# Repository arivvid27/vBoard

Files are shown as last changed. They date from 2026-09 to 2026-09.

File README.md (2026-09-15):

# vBoard

## Overview
This project is a custom-built mechanical keyboard created to replace a failing, non-ergonomic office keyboard used by my English teacher, which was causing him noticeable hand strain during long grading sessions. 

The goal was to build a reliable, tactile, and comfortable typing tool tailored for high-volume daily classroom use.

## Why I Built It
* **Solving a Real Problem:** Standard membrane office keyboards lack tactile feedback, force heavy bottom-outs, and offer no ergonomic support. Watching a favorite teacher struggle with physical discomfort on a broken board made this a high-impact problem to solve.
* **Hands-on Curiosity:** I had always wanted to build a custom mechanical keyboard from scratch to learn about hardware assembly, switch physics, and custom keymapping.

## Features & Specs
* **Ergonomic Layout:** Compact footprint designed to reduce unnecessary reach and wrist movement.
* **Tactile Switches:** Selected for clear physical feedback without requiring excessive actuation force, helping reduce finger fatigue.
* **Custom Keycaps:** Clean, comfortable profile designed for long typing sessions.

## What I Learned
* **Hardware Assembly:** Learned component compatibility across PCBs, plates, switches, and stabilizers, along with basic soldering and hardware assembly.
* **Ergonomics & Physical Health:** Explored how keycap profiles, switch actuation points, and board angles directly affect wrist strain and overall typing comfort.
* **Firmware Configuration:** Discovered how to program custom keymaps and function layers to streamline everyday typing and shortcut tasks.

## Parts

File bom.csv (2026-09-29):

Item Description | Unit Price ($) | Quantity Ordered | Total Price ($) | Amazon Link
EEEEE 1N4148 Through-Hole Switching Diodes (150pcs) | 5.99 | 1 | 5.99 | https://www.amazon.com/dp/B0FC289DVH
Fgruh 1120PCS M3 Socket Cap Screws Assortment Kit (Alloy Steel) | 9.99 | 1 | 9.99 | https://www.amazon.com/dp/B0FGV5FCBN
DUROCK Stabilizer V3, PCB Mount Screw-in (Smokey 100% Kit) | 22.99 | 1 | 22.99 | https://www.amazon.com/dp/B0B2RXR22X
DUROCK MX Hotswap PCB Sockets (Black, 110pcs) | 12.99 | 1 | 12.99 | https://www.amazon.com/dp/B0B4W9YMGM
HONKID Keyboard Plate Foam, Sound Dampening Poron (Black, 3mm) | 12.99 | 1 | 12.99 | https://www.amazon.com/dp/B0B4JXKNDQ
HONKID Keyboard Case Foam, Sound Dampening Poron (Black, 2mm) | 11.99 | 1 | 11.99 | https://www.amazon.com/dp/B0B151N6V4
GUNMJO Pro Custom Coiled USB C Cable with Aviator (White, 1.5M) | 19.99 | 1 | 19.99 | https://www.amazon.com/dp/B09F5YBH6Z
New Fashion Kingdom Stainless Steel Keycap & Switch Puller Kit | 5.98 | 1 | 5.98 | https://www.amazon.com/dp/B08TSSJ8Q3
Womier PBT Custom Blue Keycaps Set (Cherry Profile, 138 Keys) | 16.99 | 1 | 16.99 | https://www.amazon.com/dp/B0D3BW6R11
Akko V3 Creamy Blue Pro Tactile Switches (45pcs per box) | 10.39 | 3 | 31.17 | https://www.amazon.com/dp/B0C3H7PR1Z
Heat-Set Threaded Inserts M3 Heat Set Insert | 8.99 | 1 | 8.99 | https://www.amazon.com/gp/product/B0CS6VZYL8
Bumper Pads Self-Adhesive | 9.09 | 1 | 9.09 | https://www.amazon.com/gp/product/B0CF5CX3M3
Brass Flat Bar 6in x 2in x 0.12in | 11.89 | 1 | 11.89 | https://www.amazon.com/gp/product/B0F31ZW3QQ
Orpheus Pico (RP2040) | ?? | 1 | ?? | ??

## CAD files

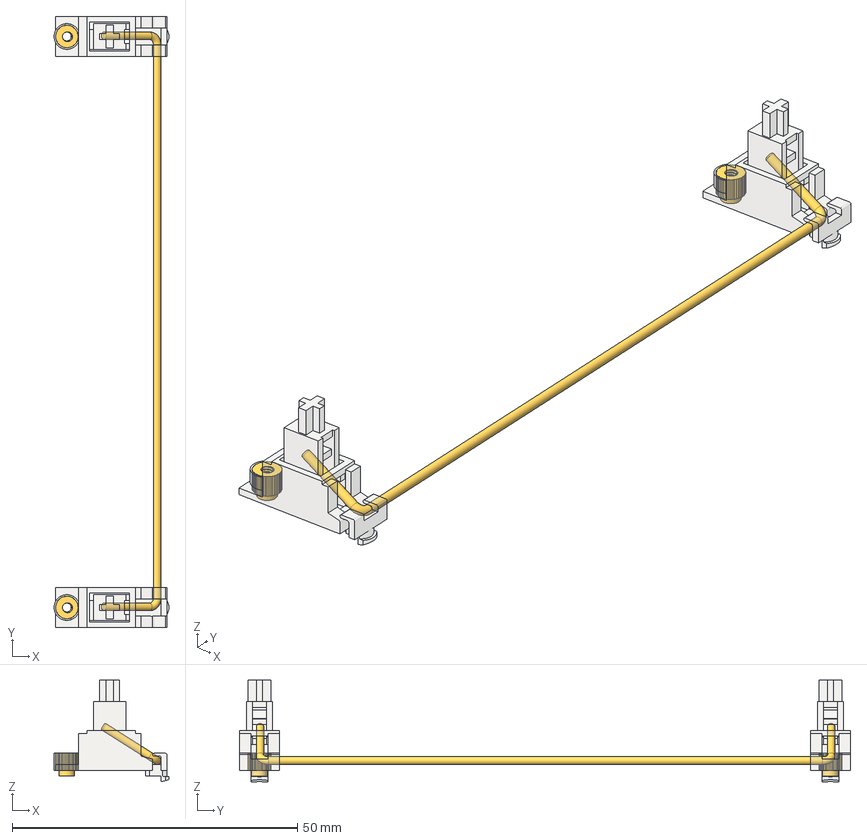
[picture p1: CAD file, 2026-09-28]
CAD FILES/6.25U Stabilizer.step
20.1 x 107.0 x 17.8 mm
Stabilizer Housing x 2
M2 Insert x 2
Stabilizer Insert x 2
6.25U Stabilizer Bar

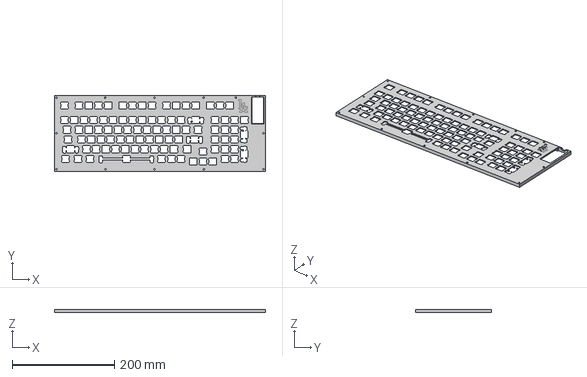
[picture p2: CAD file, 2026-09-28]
CAD FILES/FINAL/Switch Plate.step
413.5 x 148.4 x 6.50 mm

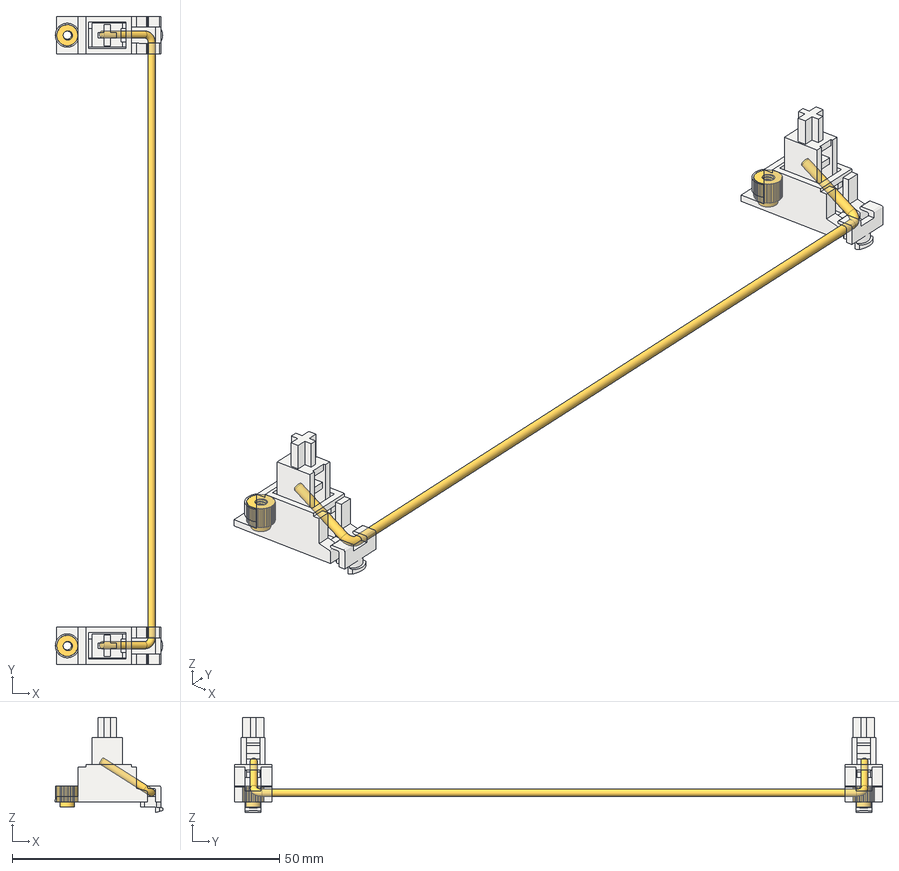
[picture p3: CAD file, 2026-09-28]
CAD FILES/7U Stabilizer.step
20.1 x 121.3 x 17.8 mm
Stabilizer Housing x 2
M2 Insert x 2
Stabilizer Insert x 2
7U Stabilizer Bar

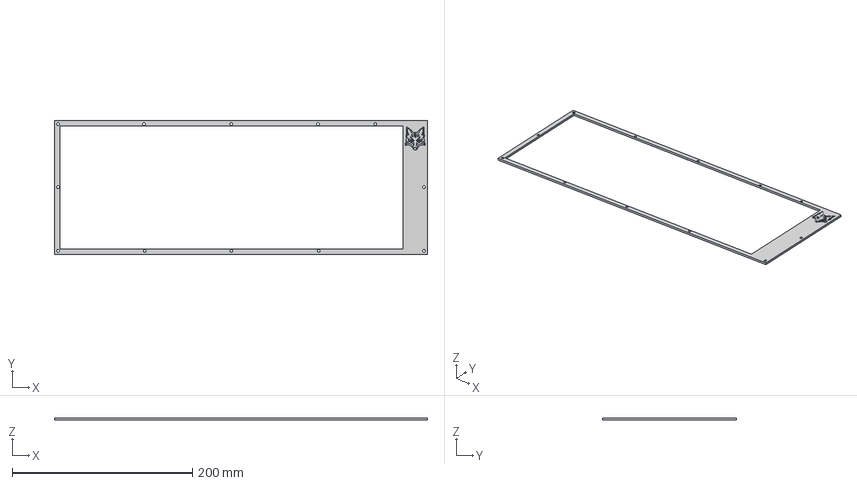
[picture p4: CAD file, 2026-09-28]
CAD FILES/FINAL/Top Frame.step
413.5 x 148.4 x 2.50 mm

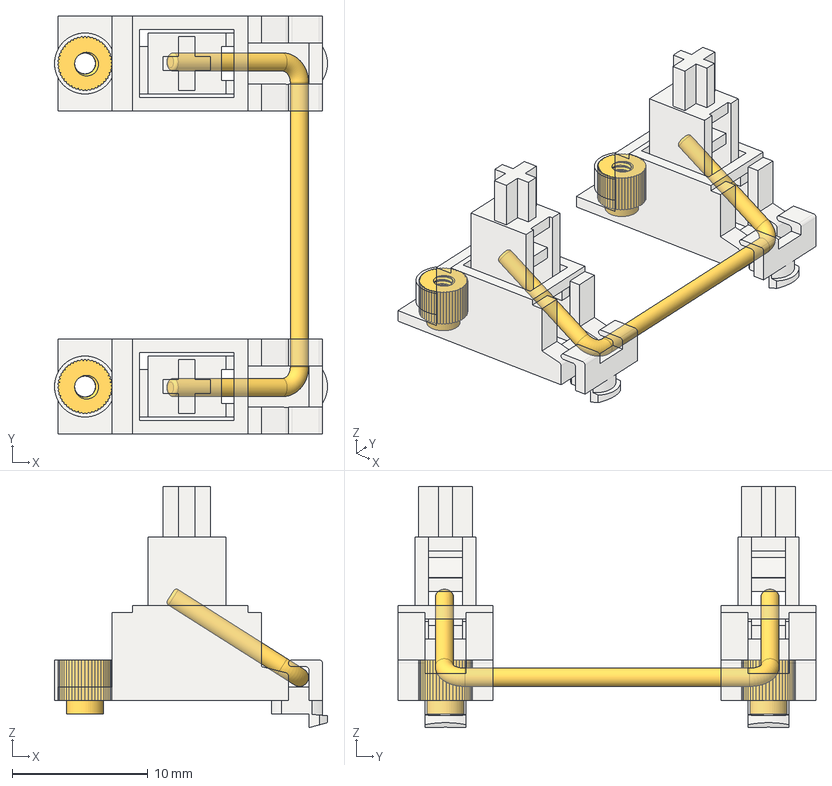
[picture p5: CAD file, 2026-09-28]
CAD FILES/2U Stabilizer.step
20.1 x 30.8 x 17.8 mm
Stabilizer Housing x 2
M2 Insert x 2
Stabilizer Insert x 2
2U Stabilizer Bar

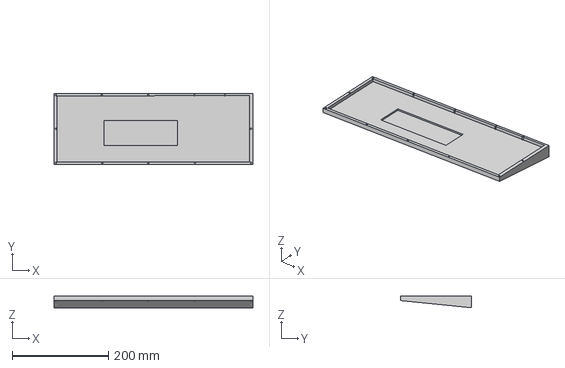
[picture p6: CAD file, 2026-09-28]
CAD FILES/FINAL/Bottom Plate.step
413.5 x 148.4 x 23.9 mm

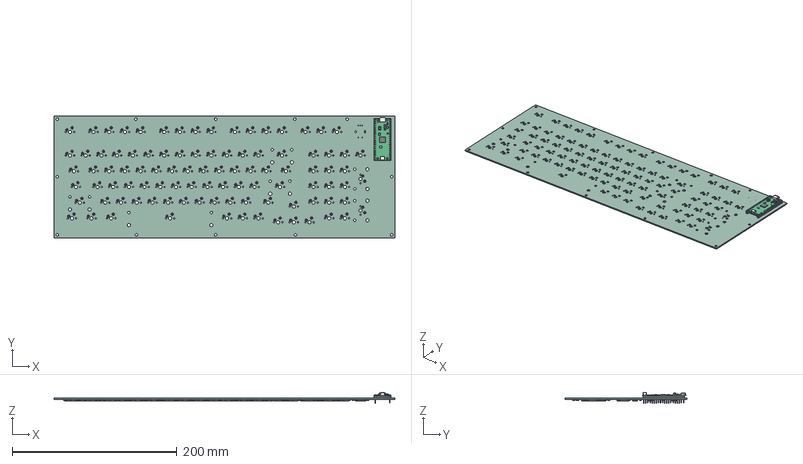
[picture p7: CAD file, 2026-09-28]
CAD FILES/vBoard.step
413.5 x 148.4 x 12.8 mm
RaspberryPi_Pico_H_Module_KiCad
RaspberryPi_Pico_Header_DIP-40_H2.54mm_KiCad
Contact x 194
D_SOD-123 x 98
vBoard_PCB

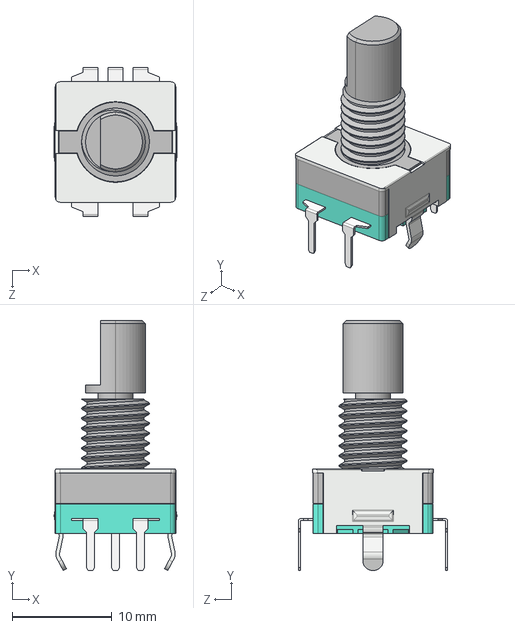
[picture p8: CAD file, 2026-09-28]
CAD FILES/EC11.STEP
12.3 x 25.1 x 15.0 mm

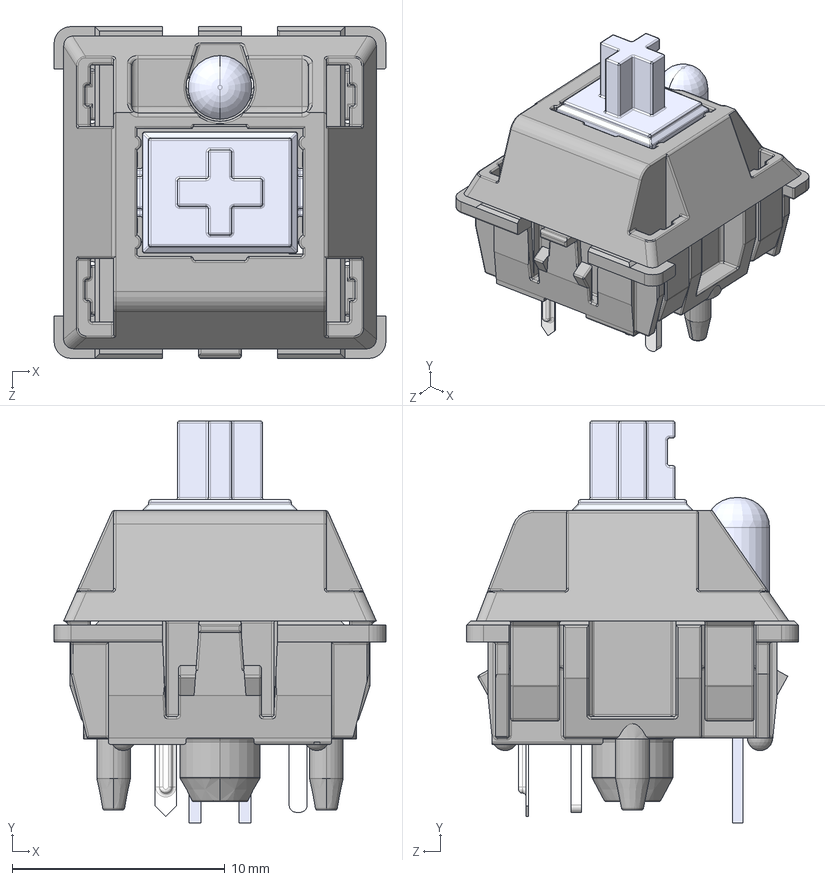
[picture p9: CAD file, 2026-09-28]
CAD FILES/MX.STEP
15.6 x 18.9 x 15.6 mm
MX 轴 按键′_ü___¨1
MX 轴 轴体áì_¨￠¨__
MX粣 拸簽LEDLEDLED
MX轴 轴体 底部 μ×2__默认_á2____è_
针脚___默认__è_

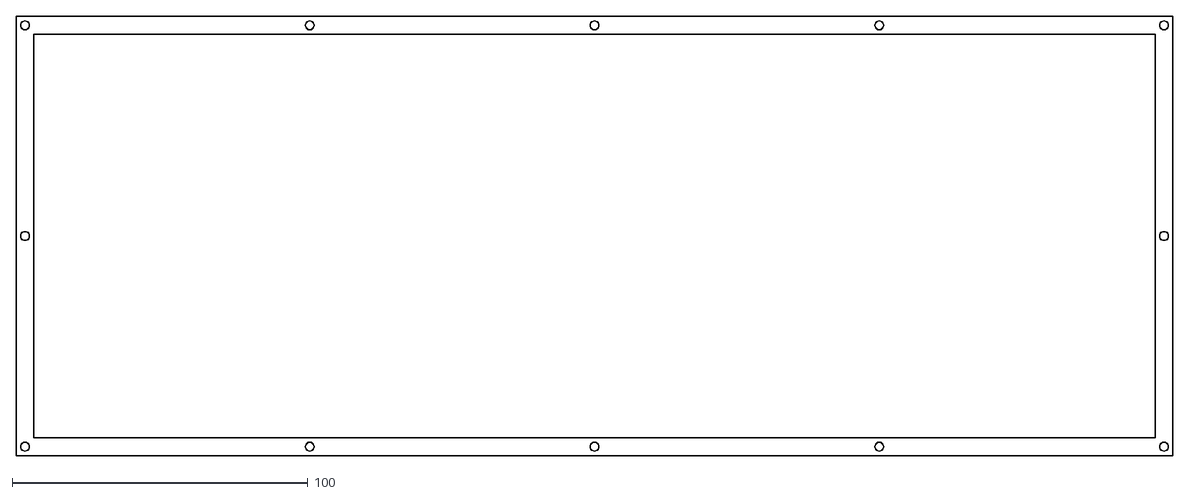
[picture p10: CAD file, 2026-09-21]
CAD FILES/closerlayer.dxf
391.5 x 148.6

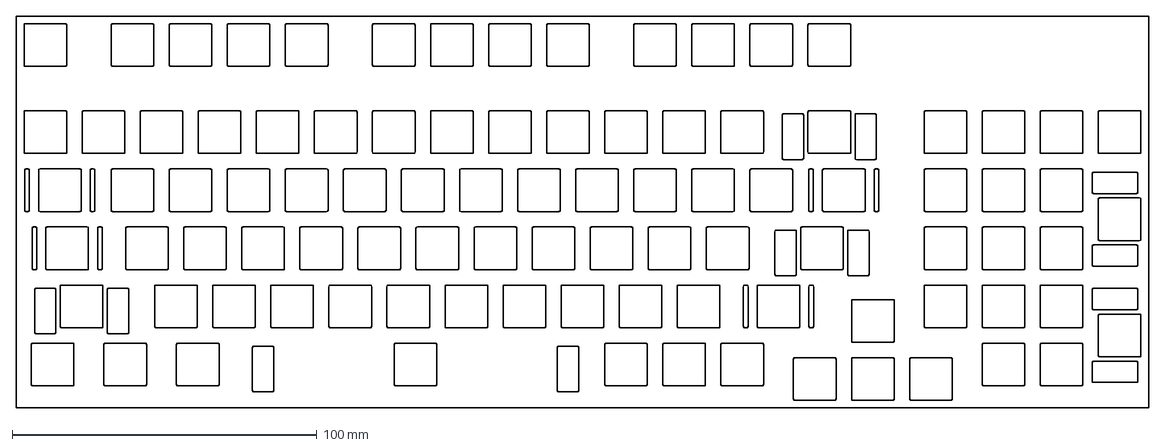
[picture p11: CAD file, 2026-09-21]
CAD FILES/switchlayer.dxf
371.5 x 128.6 mm

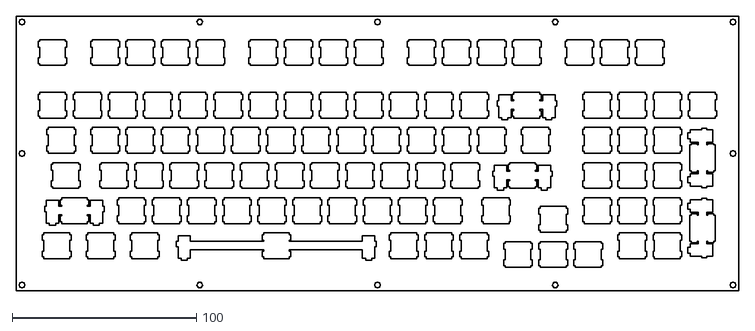
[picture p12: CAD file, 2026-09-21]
CAD FILES/switchlayerv2.dxf
391.5 x 148.6

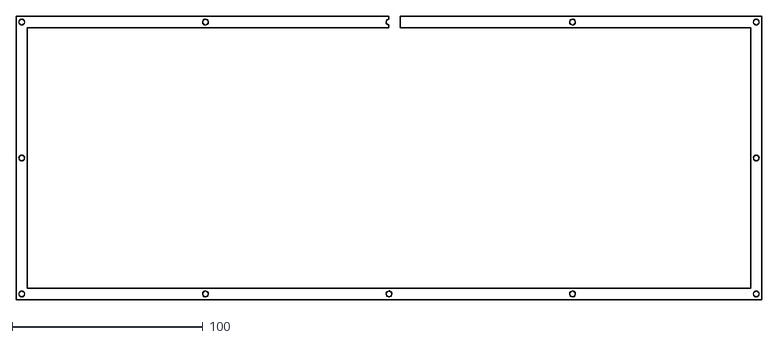
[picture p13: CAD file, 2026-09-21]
CAD FILES/openlayer.dxf
391.5 x 148.6

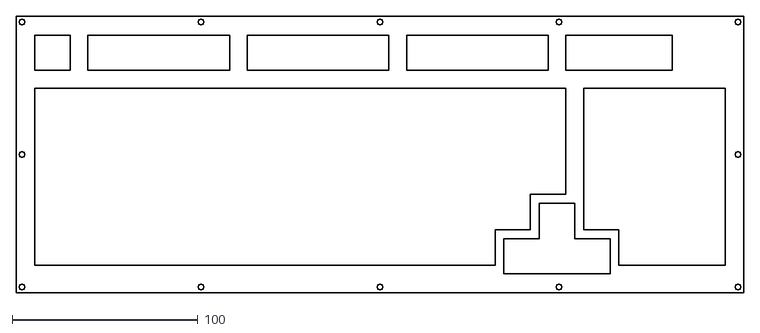
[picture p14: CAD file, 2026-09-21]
CAD FILES/toplayer.dxf
391.5 x 148.6

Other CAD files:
CAD FILES/botplate.dxf

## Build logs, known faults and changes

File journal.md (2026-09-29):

# vBoard - Build Journal

A running log of me building vBoard, a 96% / 1800-compact mechanical keyboard for my English teacher. Running an Orpheus Pico (RP2040) and RMK for firmware.

Times are rough, i just eyeball it and round to the nearest half hour.

---

## Sept 1 - Getting the idea down / research

Spent the first bit just figuring out what i actually want to build. My english teacher's office keyboard is basically falling apart and he's always complaining his hands hurt after grading, so i figured a custom mech board would be a cool thing to make for him. Watched a bunch of youtube build vids and read some geekhack + keebtalk threads to get a feel for what im getting into.

Also looked into layouts. I want something that keeps the numpad since he's entering grades all day, but i dont want a full fat fullsize. Landed on a 96% / 1800-compact. You get the numpad and arrows but everything is smushed together so it takes way less desk space. Seems perfect for his cramped desk.

~1 hr

---

## Sept 2 - Layout decisions + controller pick

Kept going on the 96% thing. Made a rough list in my notes of everything i think i'll need - pcb, plate, case, switches, stabs, keycaps, diodes, sockets, controller. Realized theres a LOT of little parts i wasnt thinking about (screws, foam, etc).

Big decision today was the controller. Instead of designing around a raw rp2040 chip and dealing with the usb + crystal + power stuff myself, im gonna use an Orpheus Pico. Its basically a rpi pico footprint running the RP2040 so i can socket it and not have to reflow a tiny qfn chip on my first ever pcb. Way less scary. Definately going with RMK for the firmware too since its rust based and i want to learn rust anyway, and it supports the rp2040 fine.

~0.5 hr

---

## Sept 3 - KiCad install + libraries (setup)

Downloaded and installed KiCad. Took a little while cuz the installer is chonky. Then spent most of the time getting libraries set up - grabbed the keyswitch kicad library and the kbd footprint libs so i have MX hotswap footprints and stab cutouts ready to go. Also pulled in a diode footprint set.

Had a dumb issue where kicad couldnt find the footprint tables, had to go into preferences and manually point it at the library paths. Fixed eventually. Made a github repo for the project too so everything is backed up.

~1 hr (setup)

---

## Sept 4 - Figuring out the CAD side (setup)

The case is gonna be a stacked/sandwich design - a bunch of flat layers screwed together with M3 screws. For now im not doing any 3d modeling, just 2d drawings of each layer that i can send off to get laser cut. So this session was me figuring out my drawing workflow and how to get clean DXF profiles out.

Im a software person, not a mechanical one, so honestly all of this cad stuff is new to me. Did a couple beginner 2d sketching tutorials so my outlines come out as proper closed loops. No real drawing yet, just getting my head around it.

~1 hr (setup)

---

## Sept 5 - BOM (setup)

Sat down and actually built out my bill of materials. Went thru amazon and picked out everything, put it in a bom.csv so i can track prices. Heres the gist:

- SK6812-E reverse mount rgb leds (for per key rgb, the reverse mount ones shine thru the switch)
- 1N4148 diodes for the matrix
- M3 socket cap screw kit for holding the case layers together
- Durock V3 screw in stabilizers (smokey)
- Durock MX hotswap sockets so i dont have to solder every switch
- plate foam (3mm poron) + case foam (2mm poron) for sound
- coiled usb c cable cuz it looks cool
- switch + keycap puller kit
- Womier PBT keycaps, cherry profile, blue
- Akko V3 Creamy Blue Pro tactile switches (got 3 boxes, 45 each = 135, enough for a 96% with spares)

Total came out to around $160ish which isnt bad. Double checked the switch count against how many keys a 1800 layout has, should be fine with a few extra.

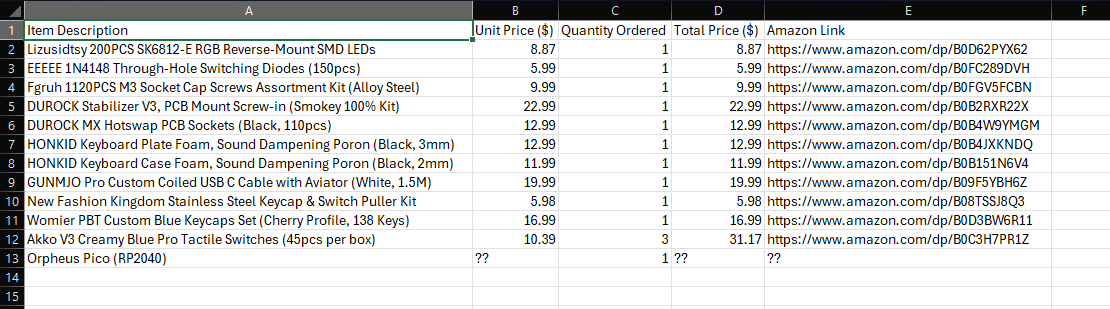
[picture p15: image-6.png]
BOM


~1 hr (setup)

---

## Sept 6 - Planning the layout in KLE + CAD drawings start

Built the exact 96% layout in keyboard layout editor (KLE) first so i know where every key sits and what size it is. Getting the 1800 arrangement right is fiddly - the arrow keys and nav cluster get tucked in tight and the numpad has to line up on the right. Once it looked right i used it as my reference for drawing.

Then started the actual case layer drawings. These are just 2d drawings for now, one profile per layer, that ill get laser cut. Got the outer profile done first so i can reuse it across every layer. This is my first time really doing cad so its slow going, lots of undo.

~2 hr

---

## Sept 8 - More layer drawings

Kept going on the layers. Reused the outer profile across the stack:
- top layer (bezel that frames the keycaps)
- switch layer / plate (all the switch cutouts)
- open + closer layers (spacers for depth / to hide the pcb edge)
- bottom plate (the base)

Being a swe and not a mech engineer, laying out precise dimensioned cutouts is a whole different brain than writing code. Took me a while to get comfy with constraints and getting things to actually snap where i want. Got the easy layers (top, bottom, spacers) mostly done.

~2 hr

---

## Sept 9 - Switch cutout grind

The switch plate is the painful one - gotta cut a 14x14mm hole for every single switch, ~100 of them, all positioned off my KLE layout. Spent basically the whole session just placing and lining up switch cutouts. Very tedious and i kept second guessing my spacing (19.05mm grid) so i measured a bunch of times.

Got most of the switch cutouts placed. My eyes hurt lol.

~1.5 hr

---

## Sept 11 - Stabilizer cutouts

Did the stabilizer cutouts for the bigger keys (spacebar, both shifts, enter, backspace, numpad plus/enter). Looked up the official durock v3 stab cutout dimensions cuz my first attempt was just plain rectangles that were the wrong shape. Redid them properly.

Learning as i go how much little details matter in mechanical stuff - a cutout being half a mm off actually matters here, which is not something i deal with in software. Slow but getting there.

~1.5 hr

---

## Sept 13 - v2 switch layer + screw holes

Realized my switch cutouts were a hair too tight for the switch clips to actually seat, so i did a v2 of the switch layer with slightly cleaner cutouts. Then added all the M3 screw holes across the layers - corners plus a few in the middle so the plate doesnt bow.

The important part was making the screw holes line up across every single layer so one screw can pass straight thru the whole stack. Went hole by hole checking alignment. Found a couple that were off and fixed them.

~1.5 hr

---

## Sept 15 - Fitment check + DXF cleanup

Went over all the layer drawings and imagined the whole stack together - screw holes have to pass thru clean, plate cutouts have to sit over where the switches go. Fixed one hole that was off by about a mm so a screw wouldnt go straight.

Then cleaned up the DXFs for export. When you export you sometimes get little duplicate lines or tiny gaps that mess up a laser cutter, so i went thru each layer (toplayer, switchlayer + v2, openlayer, closerlayer, botplate) and made sure every profile is one closed loop with no doubles. Pushed everything to github too.

~2 hr

---

## Sept 16 - Trying to learn KiCad (its hard)

Ok so now i need to actually design the pcb and this is where im struggling. KiCad is a LOT. Spent this whole session just going thru tutorials - schematic editor, symbols, footprints, how the netlist flows into the pcb editor. Coming from software none of this workflow is intuitive to me yet.

Didnt produce anything real, just poking around and following along with a beginner keyboard pcb tutorial to try to understand the process. Definately gonna take me a few sessions before im making my own schematic.

~2 hr

---

## Sept 18 - Exported the case drawings

Exported all the layer DXFs proper and gave them one more look to sanity check the switch cutouts are all there and the right size. These are done and ready to send to a laser cutting service whenever. Feels good to have at least the whole case side basically finished even if it took forever.

~1 hr

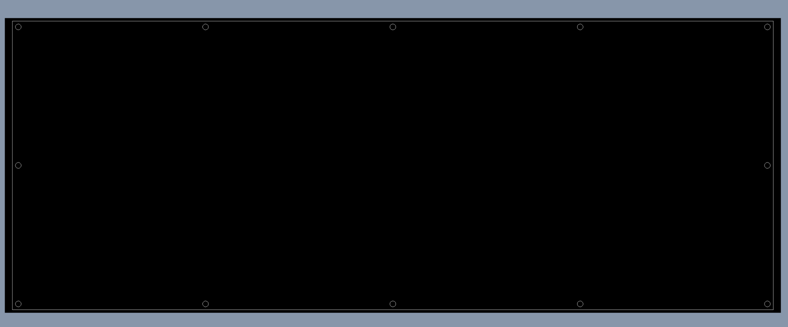
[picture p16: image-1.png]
Bottom Plate

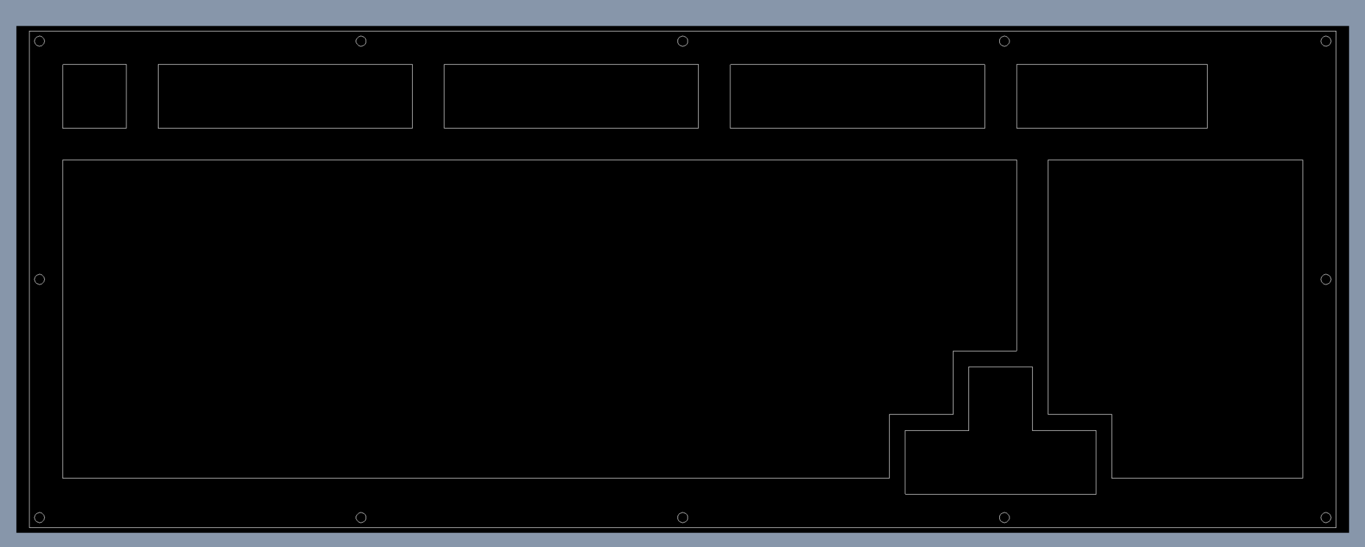
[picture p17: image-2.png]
Top Plate

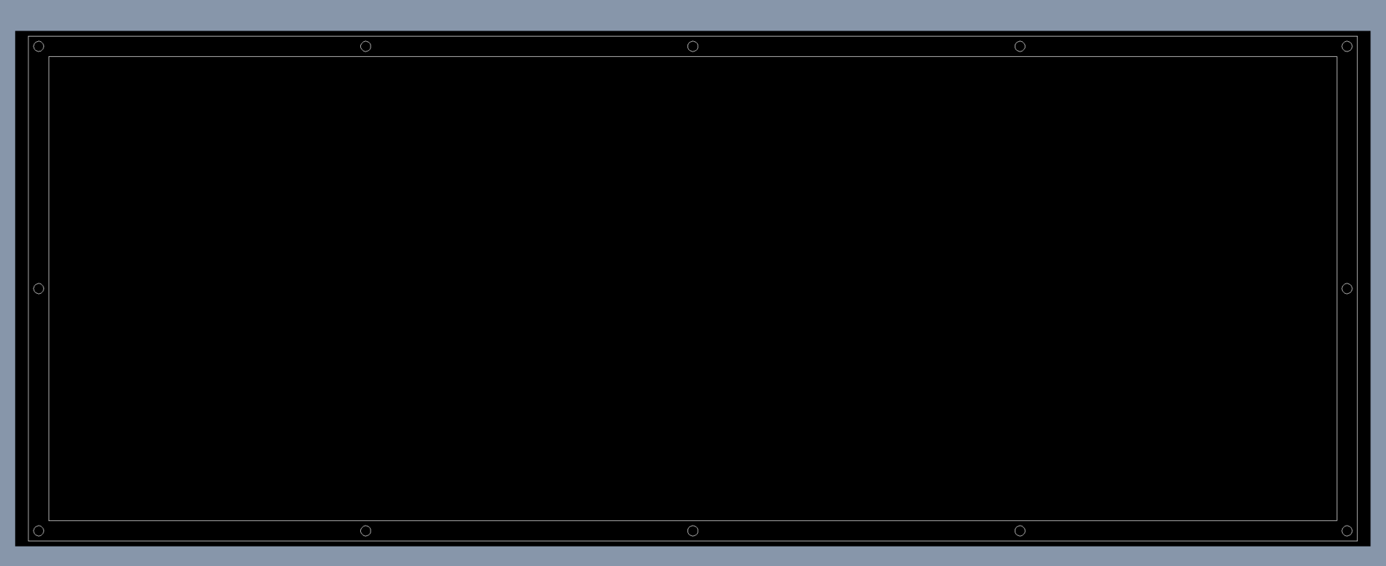
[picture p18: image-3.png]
Closed Layer

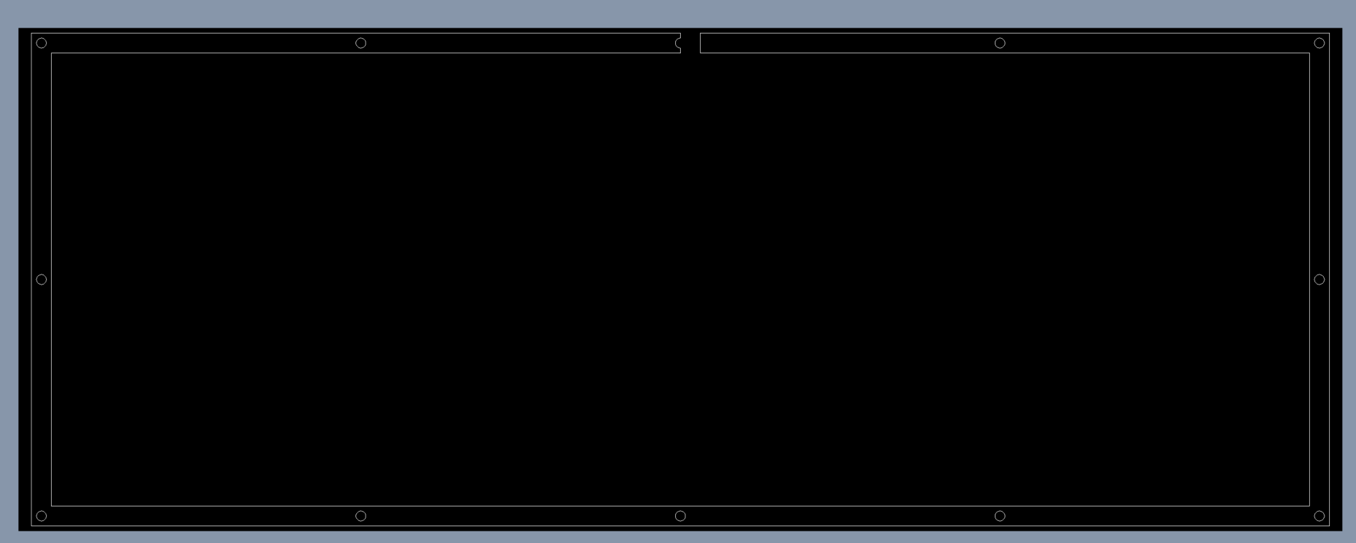
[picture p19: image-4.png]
Open Layer

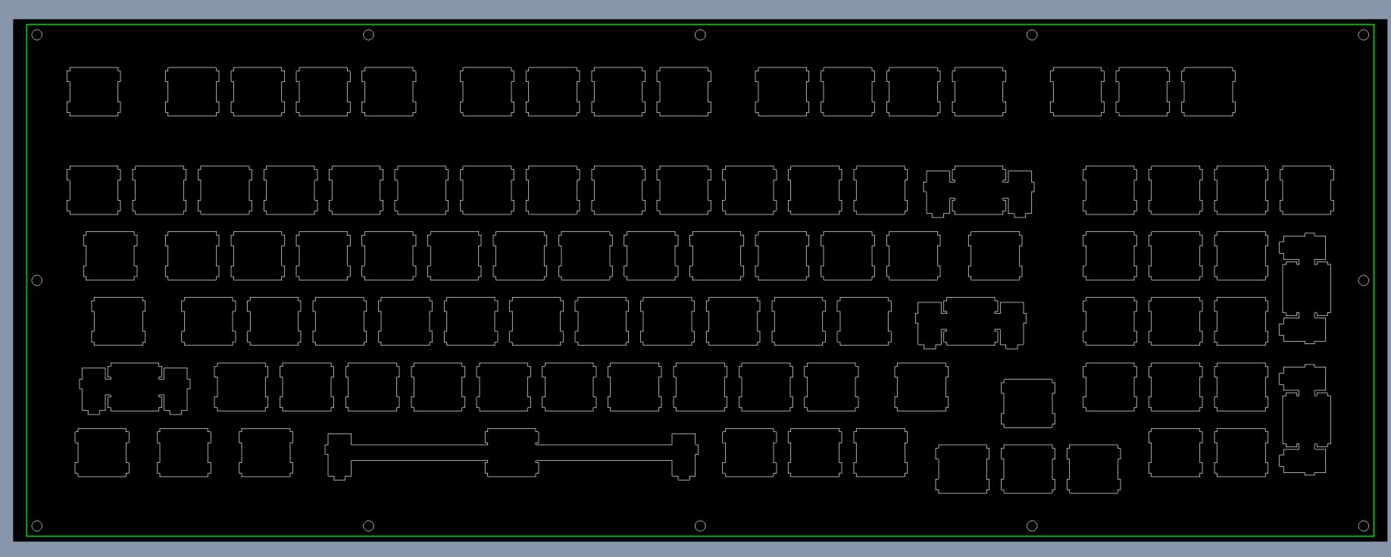
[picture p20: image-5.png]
Switch Plate


---

## Sept 19 - More KiCad learning + ordered parts

Went back to KiCad and kept learning. Started by figuring out how to the Orpheus Pico into my schems. Imported a normal RP2040 instead. Got partway thru placing the pins off the pinout but its still rough, more of a learning exercise than a finished part. Still finding the whole thing pretty hard.

Also placed my amazon orders off the bom now that the case design is locked - confirmed 135 switches covers the layout with spares, 138 keycaps covers it, and enough hotswap sockets (110) and diodes. Now i wait for parts once i get the grant thru.

~1.5 hr

---

## Next up

Where im at: BOM is done and parts are ordered, the 2d case layer drawings are done + exported. The pcb is the big remaining thing - im still learning KiCad and haven't made the real schematic yet. Still to do:

- keep learning KiCad, finish the Orpheus Pico symbol/footprint
- draw the schematic (switch matrix + diodes, sk6812 rgb chain, wire it to the pico)
- assign footprints, place switches in the 1800 layout, route the board, run DRC
- export gerbers to get the pcb made + get the case layers laser cut
- set up the RMK firmware project (rust toolchain for rp2040) and write the keymap
- solder diodes + sockets + leds, flash the pico, test the matrix
- assemble case + foam + stabs + switches + keycaps, final testing + rgb tuning

---

### Time so far

Rough running total, not exact:

- Setup (research, KiCad install, CAD workflow, BOM): ~4.5 hrs
- CAD case layer drawings (KLE, cutouts, stabs, fitment, DXF export): ~11.5 hrs
- Learning KiCad: ~3.5 hrs
- Ordering parts: ~1.5 hrs

Around 21 hrs in as of today the 20th. Most of it went into the cad since im a swe and the mechanical/drawing side is all new to me. KiCad is the wall im hitting now. Goal is 30 by the end of the month, so ~9 more hrs to go once i actually get the pcb and firmware going.

## Additional Work done on the 20th:
Oh my gosh kicad is hard.

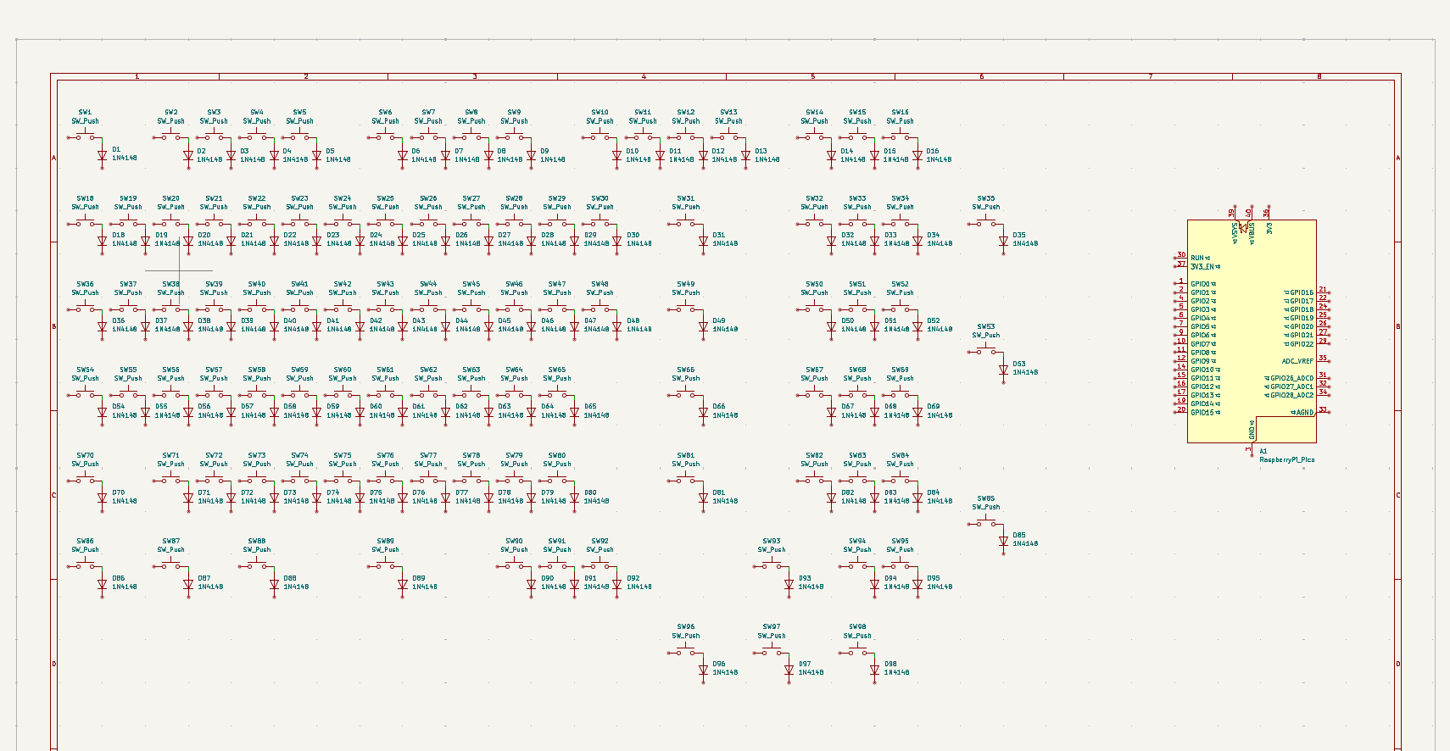
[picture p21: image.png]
Before Schem


~1.5 hr

## Sept 22 - More KiCad
I'm getting beat by trying to route my pcb.
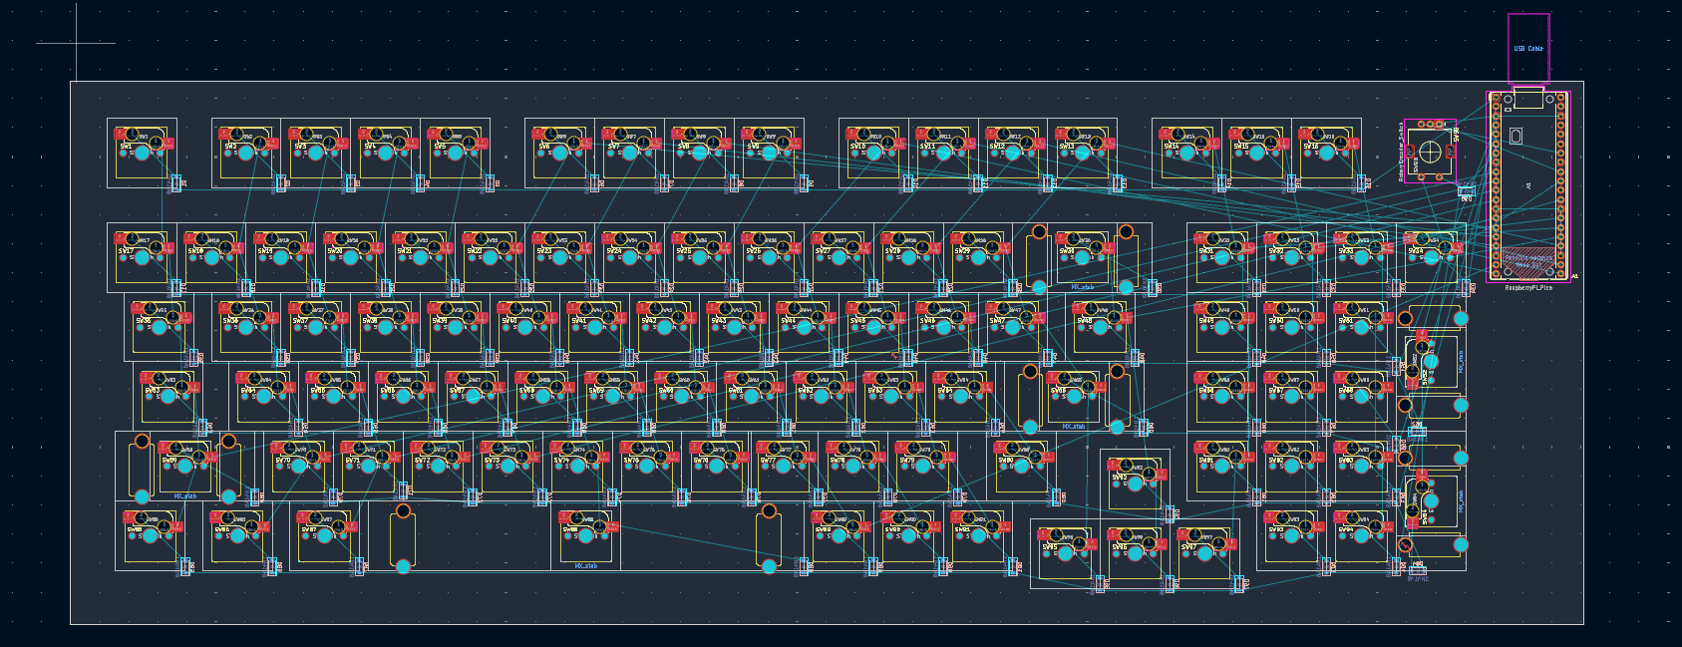
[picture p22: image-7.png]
Finished placing

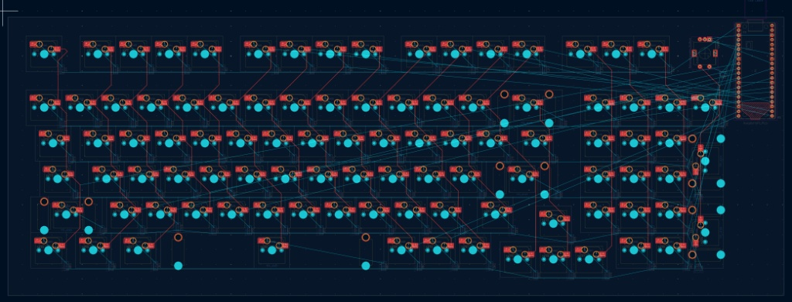
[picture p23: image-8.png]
Red Routing v1


Update at 11:52 PM:
I can not route for the love of me.
I will try to extend me edge.cut out a bit more to
allow for more room for my paths.

~8 hr

I think i'm hitting my goal by a long shot
pretty soon

new goal: 45 hours

## Sept 25 - Even More KiCad
I managed to get my B.Cu paths going. Mainly my diodes.
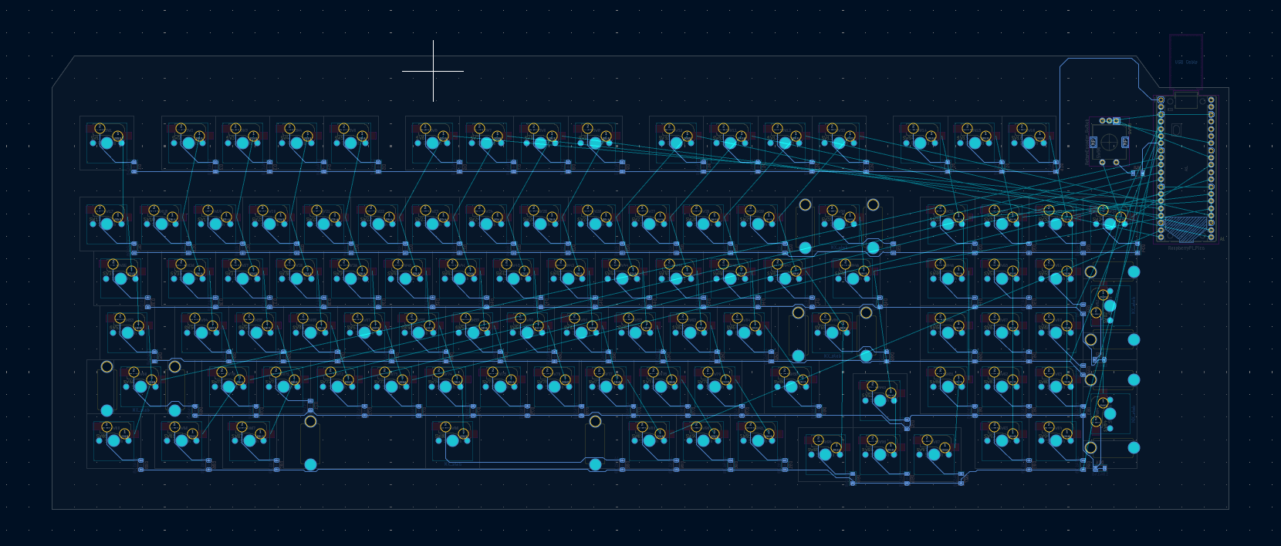
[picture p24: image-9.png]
Horizontal Rows

This requires a sort of visualization and strategy that I never thought
i would require.

~2.5 hr

## Sept 27 (PT1) - Finishing up KiCad (Finally)
I got my routings to work. With some googling, I found that I can sent
one track through multiple layers. Knowing that would have been useful a
couple days ago...
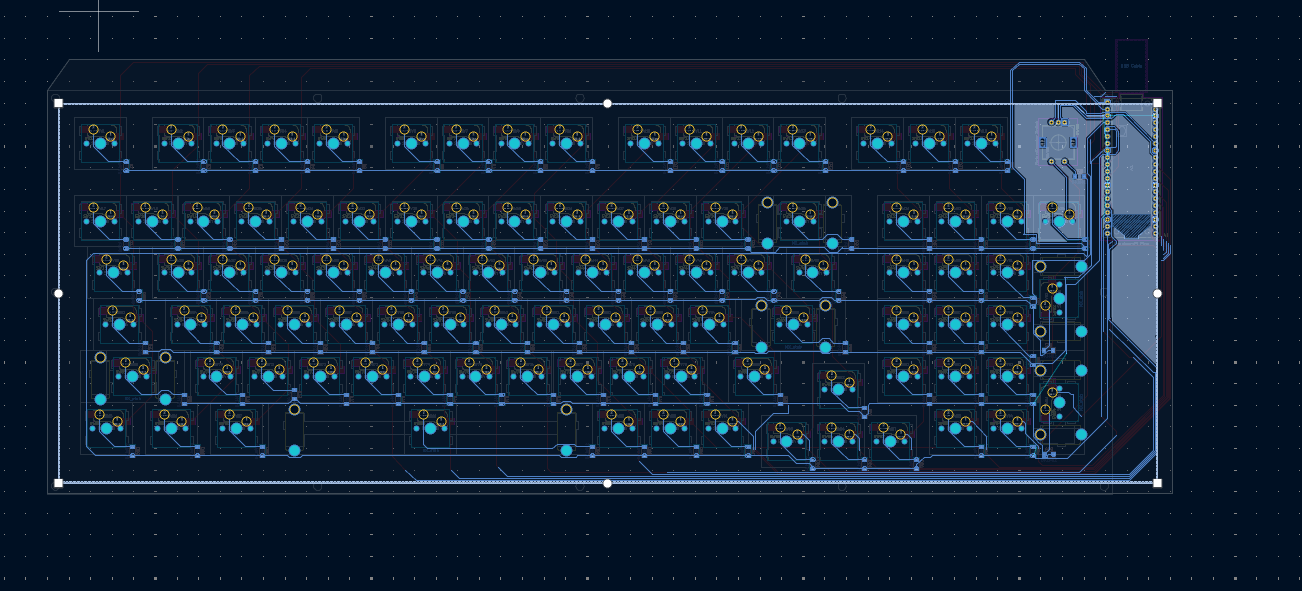
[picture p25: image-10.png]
Finished Routing


Some more googling also led me to try out a copper pour to ground my
entire keyboard. Drew a zone, did some stuff, and kaboom. The entire
thing is good to go. I just have to run a quick design check.
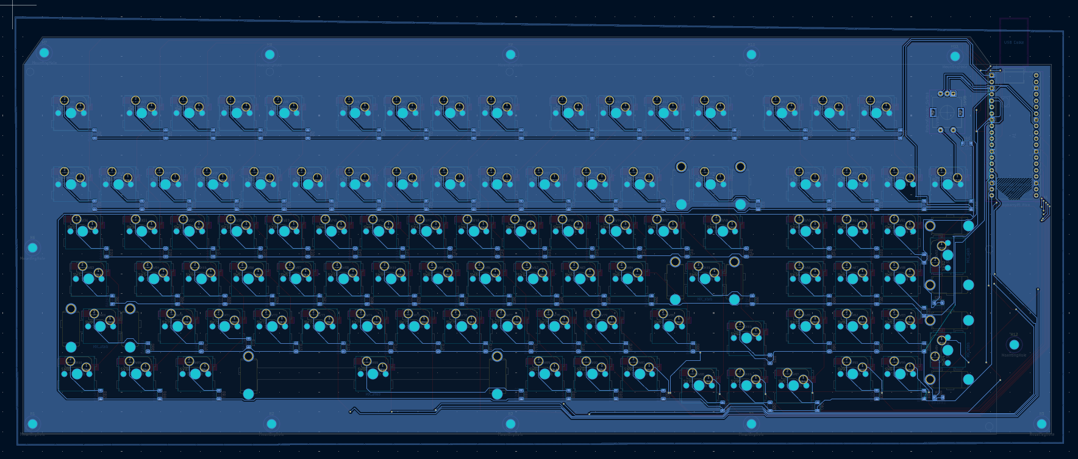
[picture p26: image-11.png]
Copper Pour


Update:
Got some errors, am gonna fix.
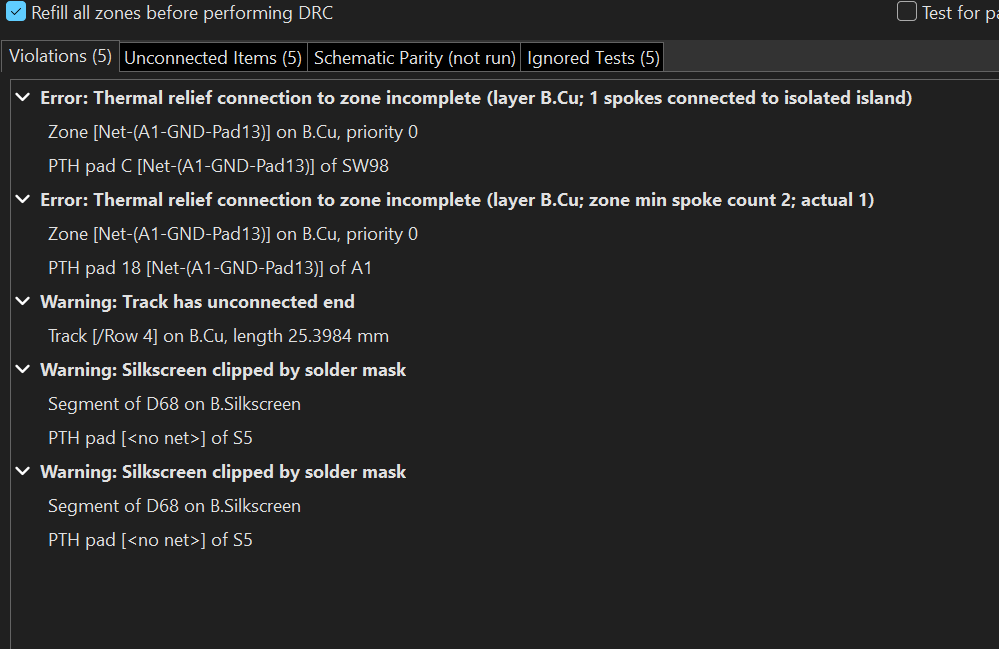
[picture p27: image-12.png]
Got a few DRC Errors

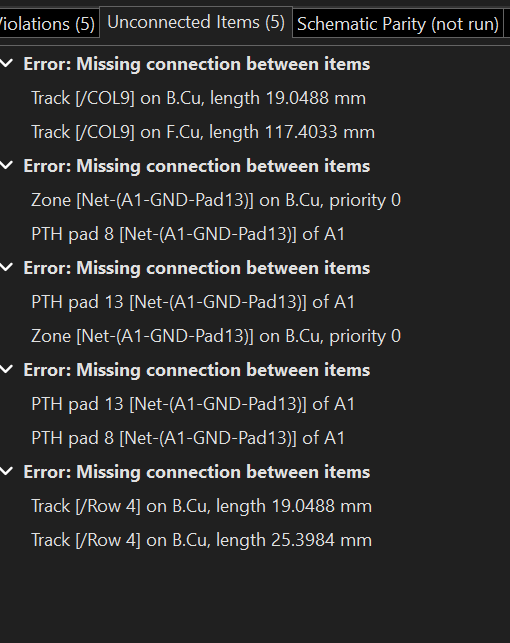
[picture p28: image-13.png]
Some more Errors


Update:
Fixed Errors. Ready to export.
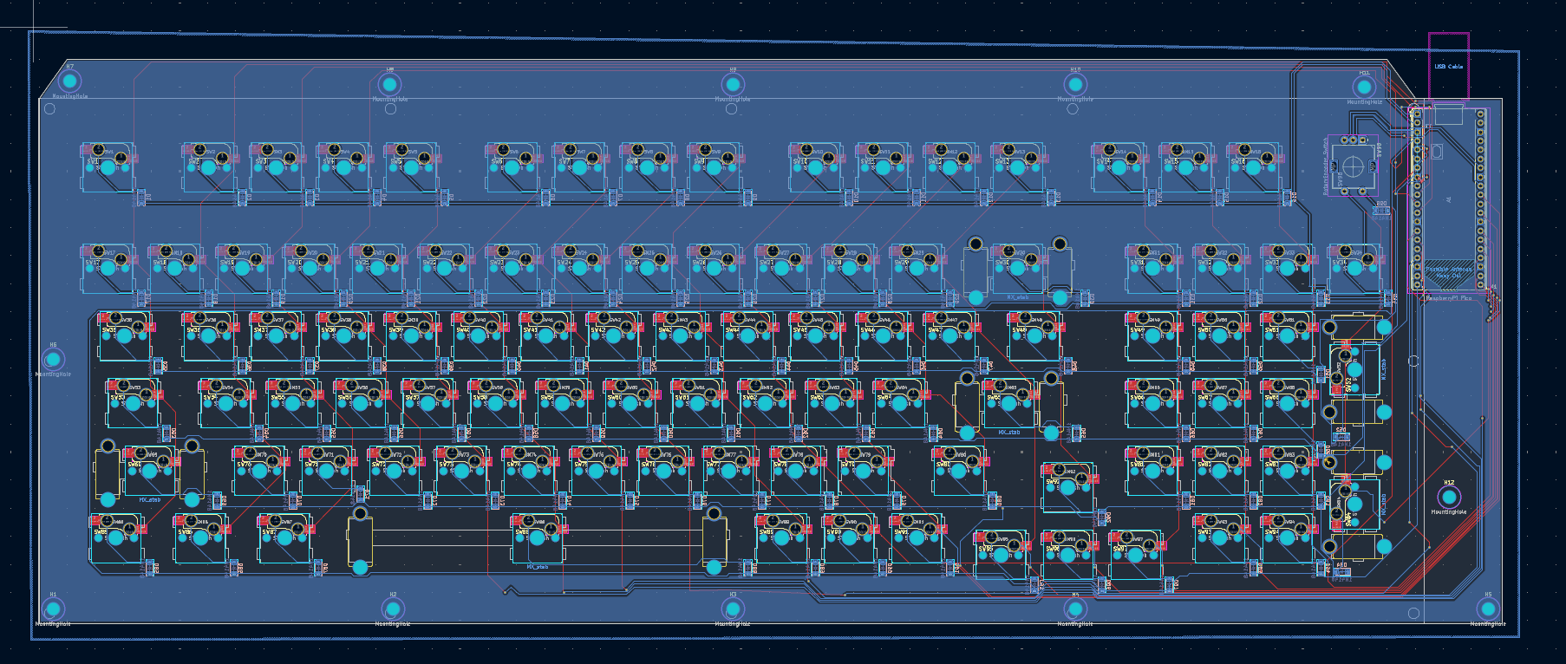
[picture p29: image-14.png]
Final and Done


Extra:
PCB Order :3
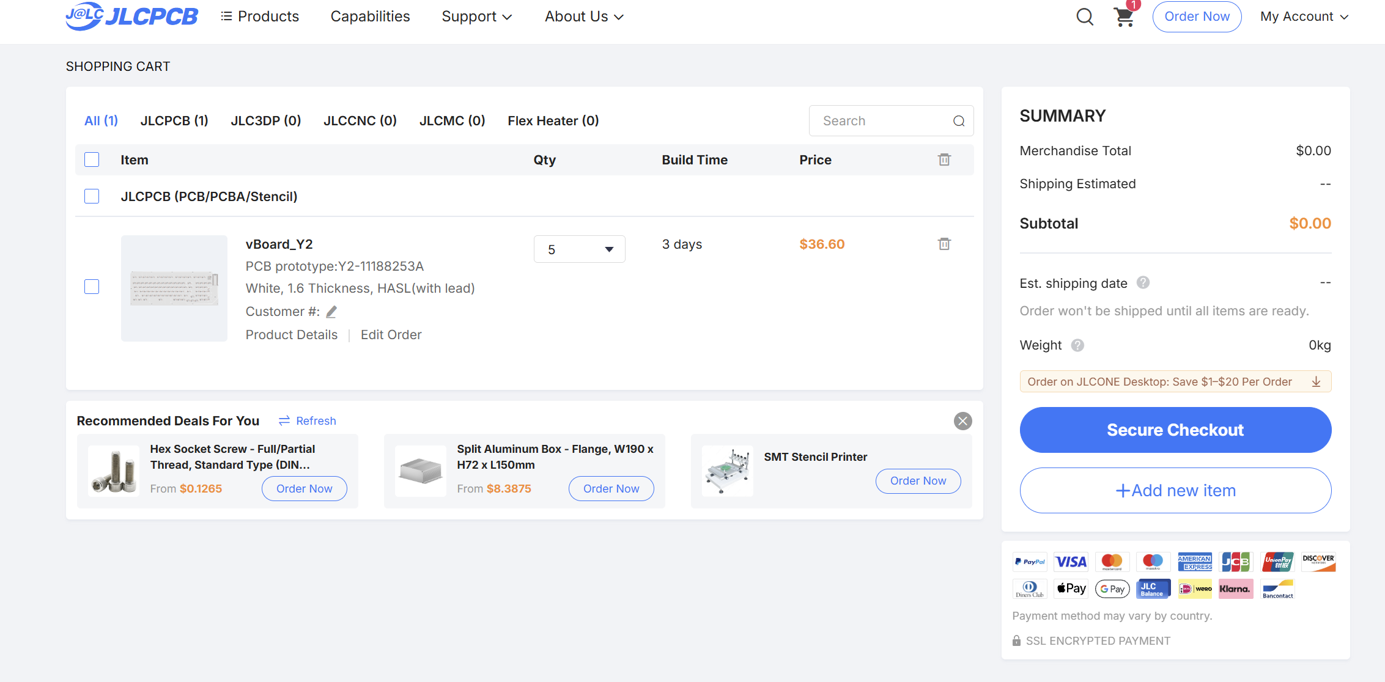
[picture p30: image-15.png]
Ordered the PCB in White


Update:
I messed up. I put my hotswaps in F.Cu. Im gonna work on it more now :[
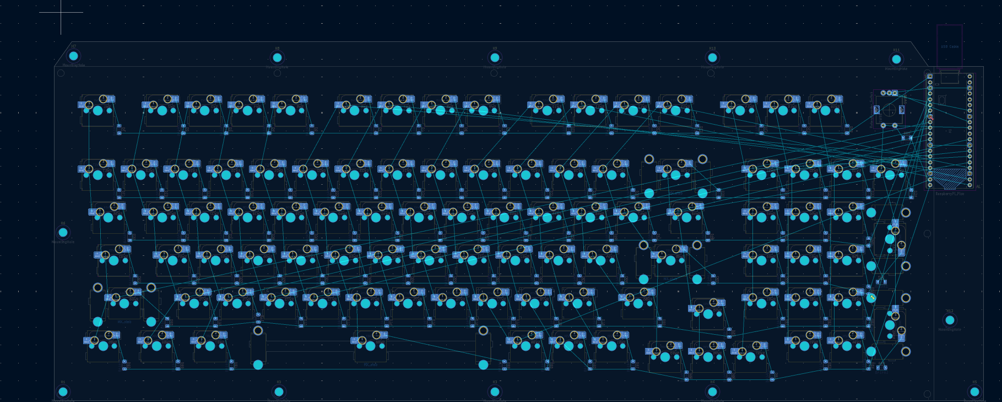
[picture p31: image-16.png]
Moved my Hotswaps to B.Cu


Now I gotta reroute everything... goodness.

~5 hr

## Sept 28 - Finished fixing my mess.
Voila. I finished the rerouting, and everything is where it should be.
I even added my decal, name and Riot ID.
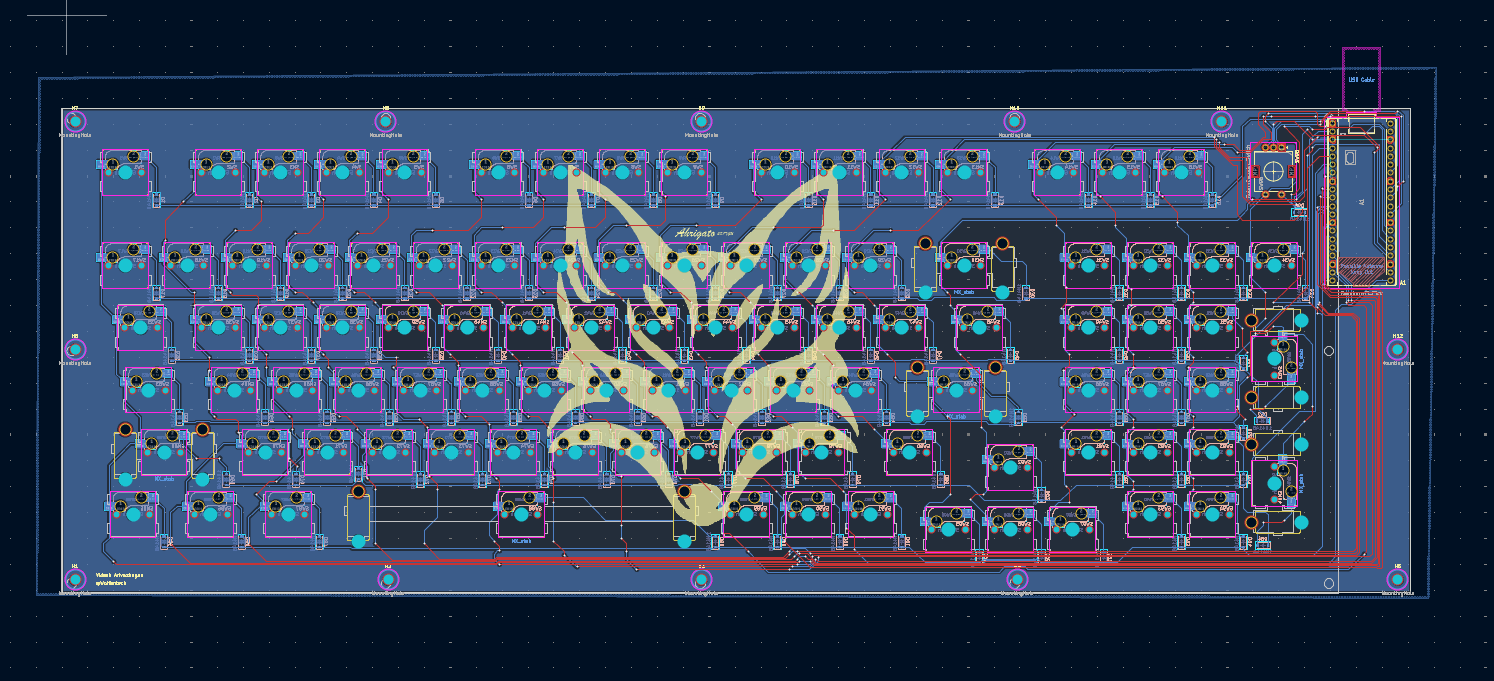
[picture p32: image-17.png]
FINALLY


~2 hr

## Sept 28 - CAD Starting
I got my actual PCB file as a .step and now I am working on putting in
all the parts digitally so I can design my case around it.
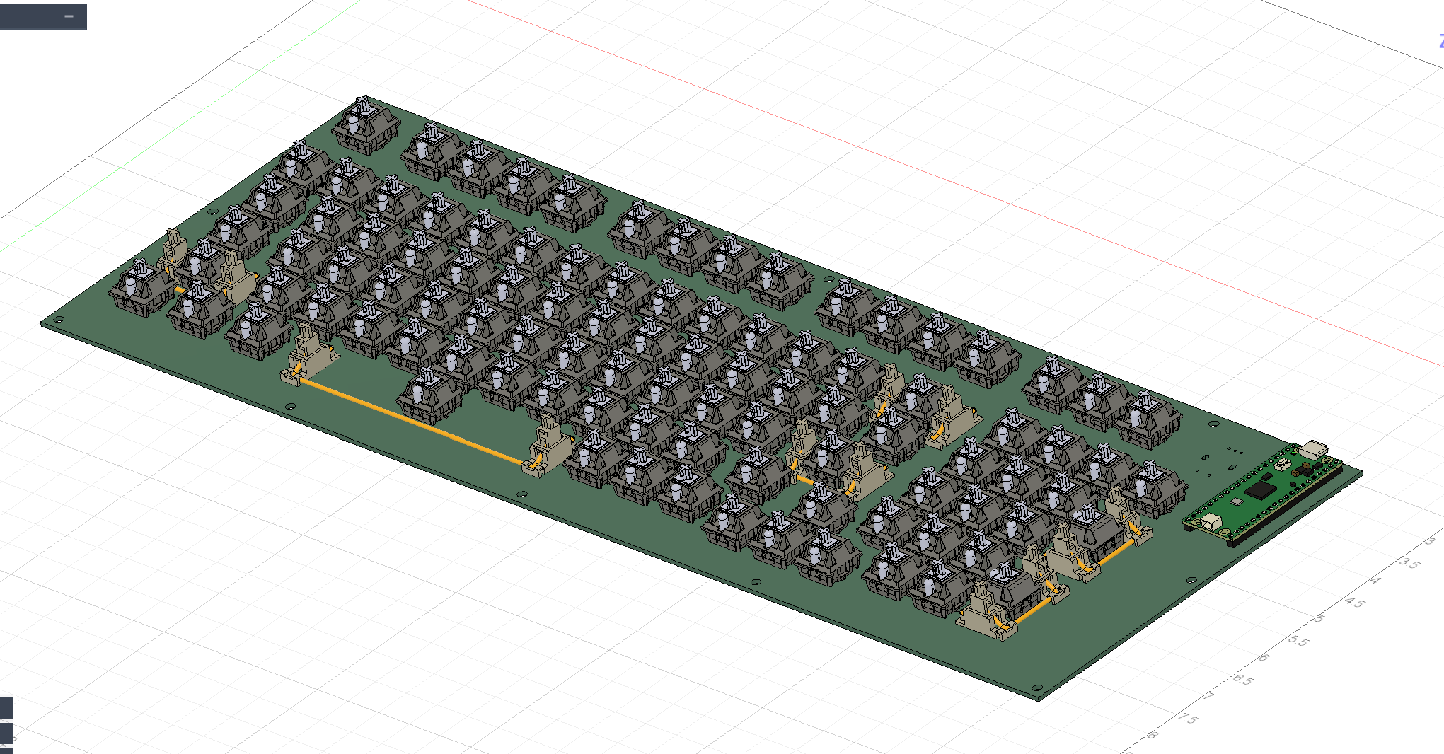
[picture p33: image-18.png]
Stabs and Switches


I finished my Cad model, after making each layer :3
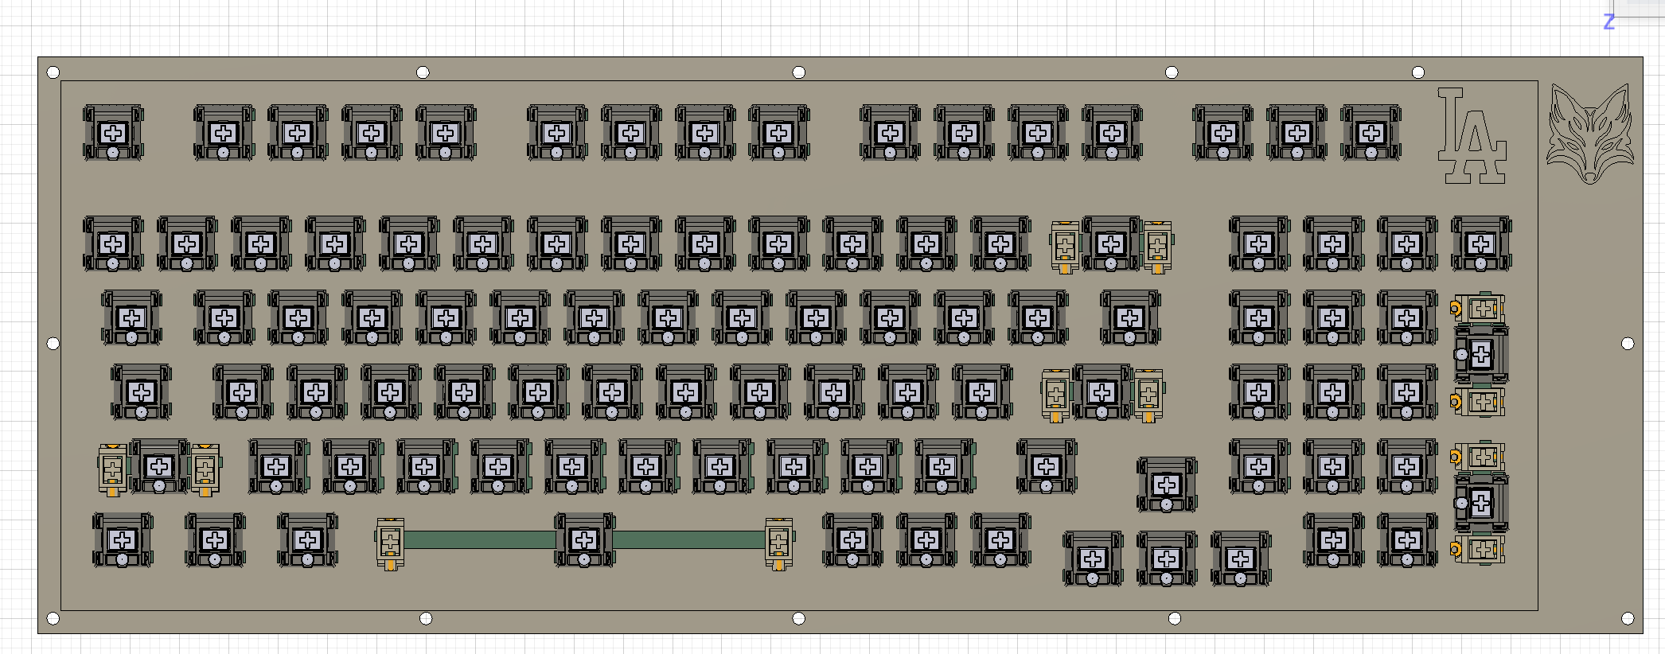
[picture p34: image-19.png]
Top

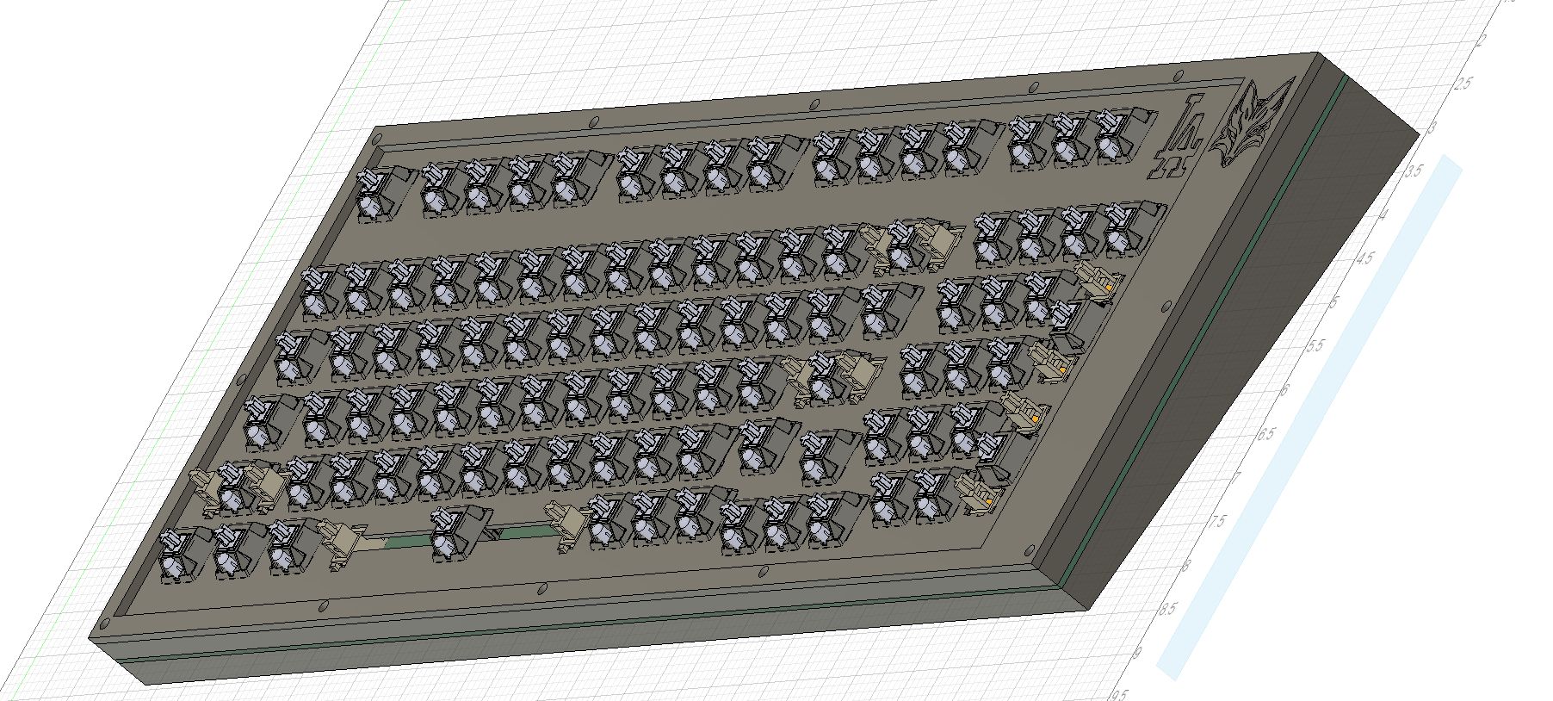
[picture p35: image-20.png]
Entire


For my own sake, here are my Pinouts
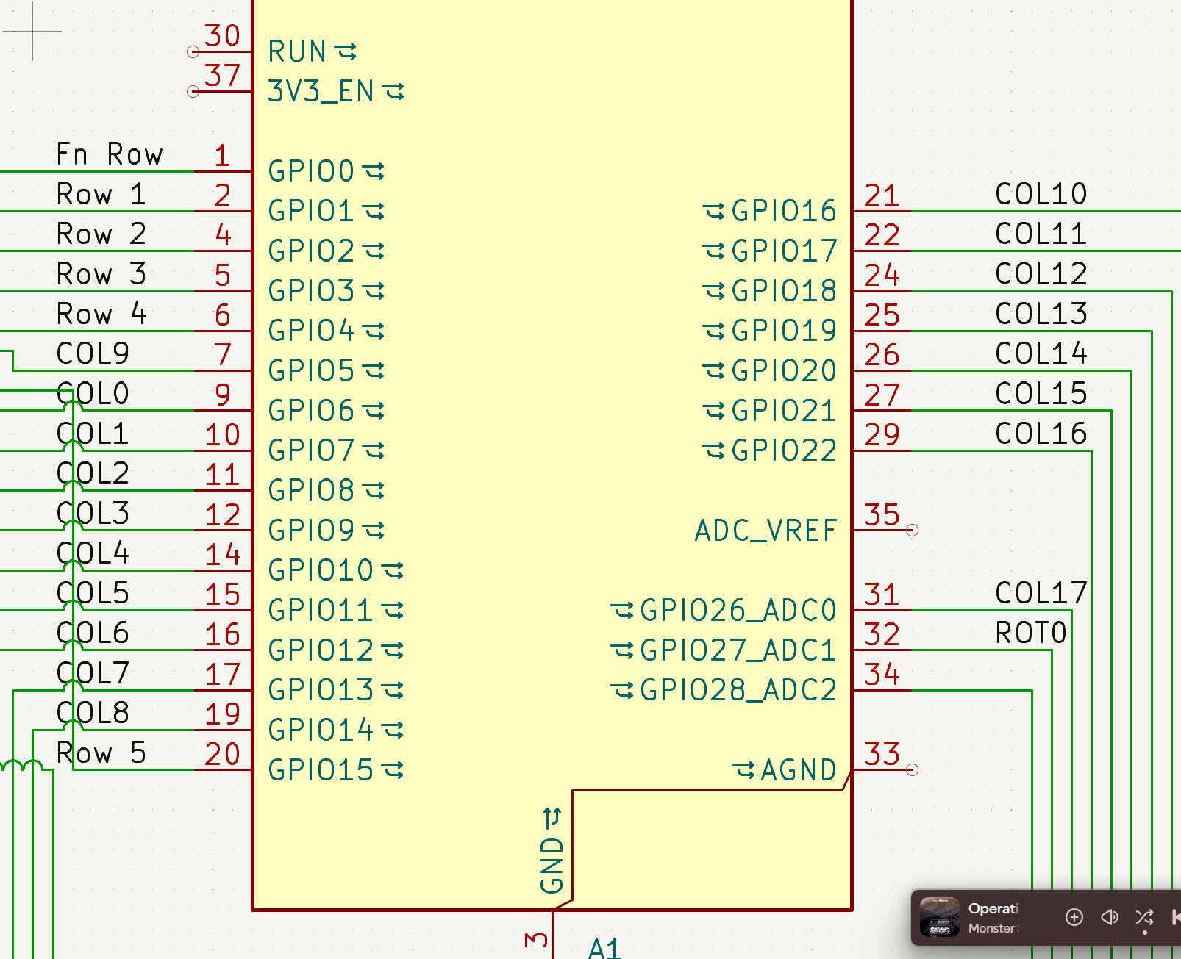
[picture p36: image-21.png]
Pinout


I'm done with my firmare. I am now just waiting on my board
and my parts to come to me with the grant :3

~8 hr

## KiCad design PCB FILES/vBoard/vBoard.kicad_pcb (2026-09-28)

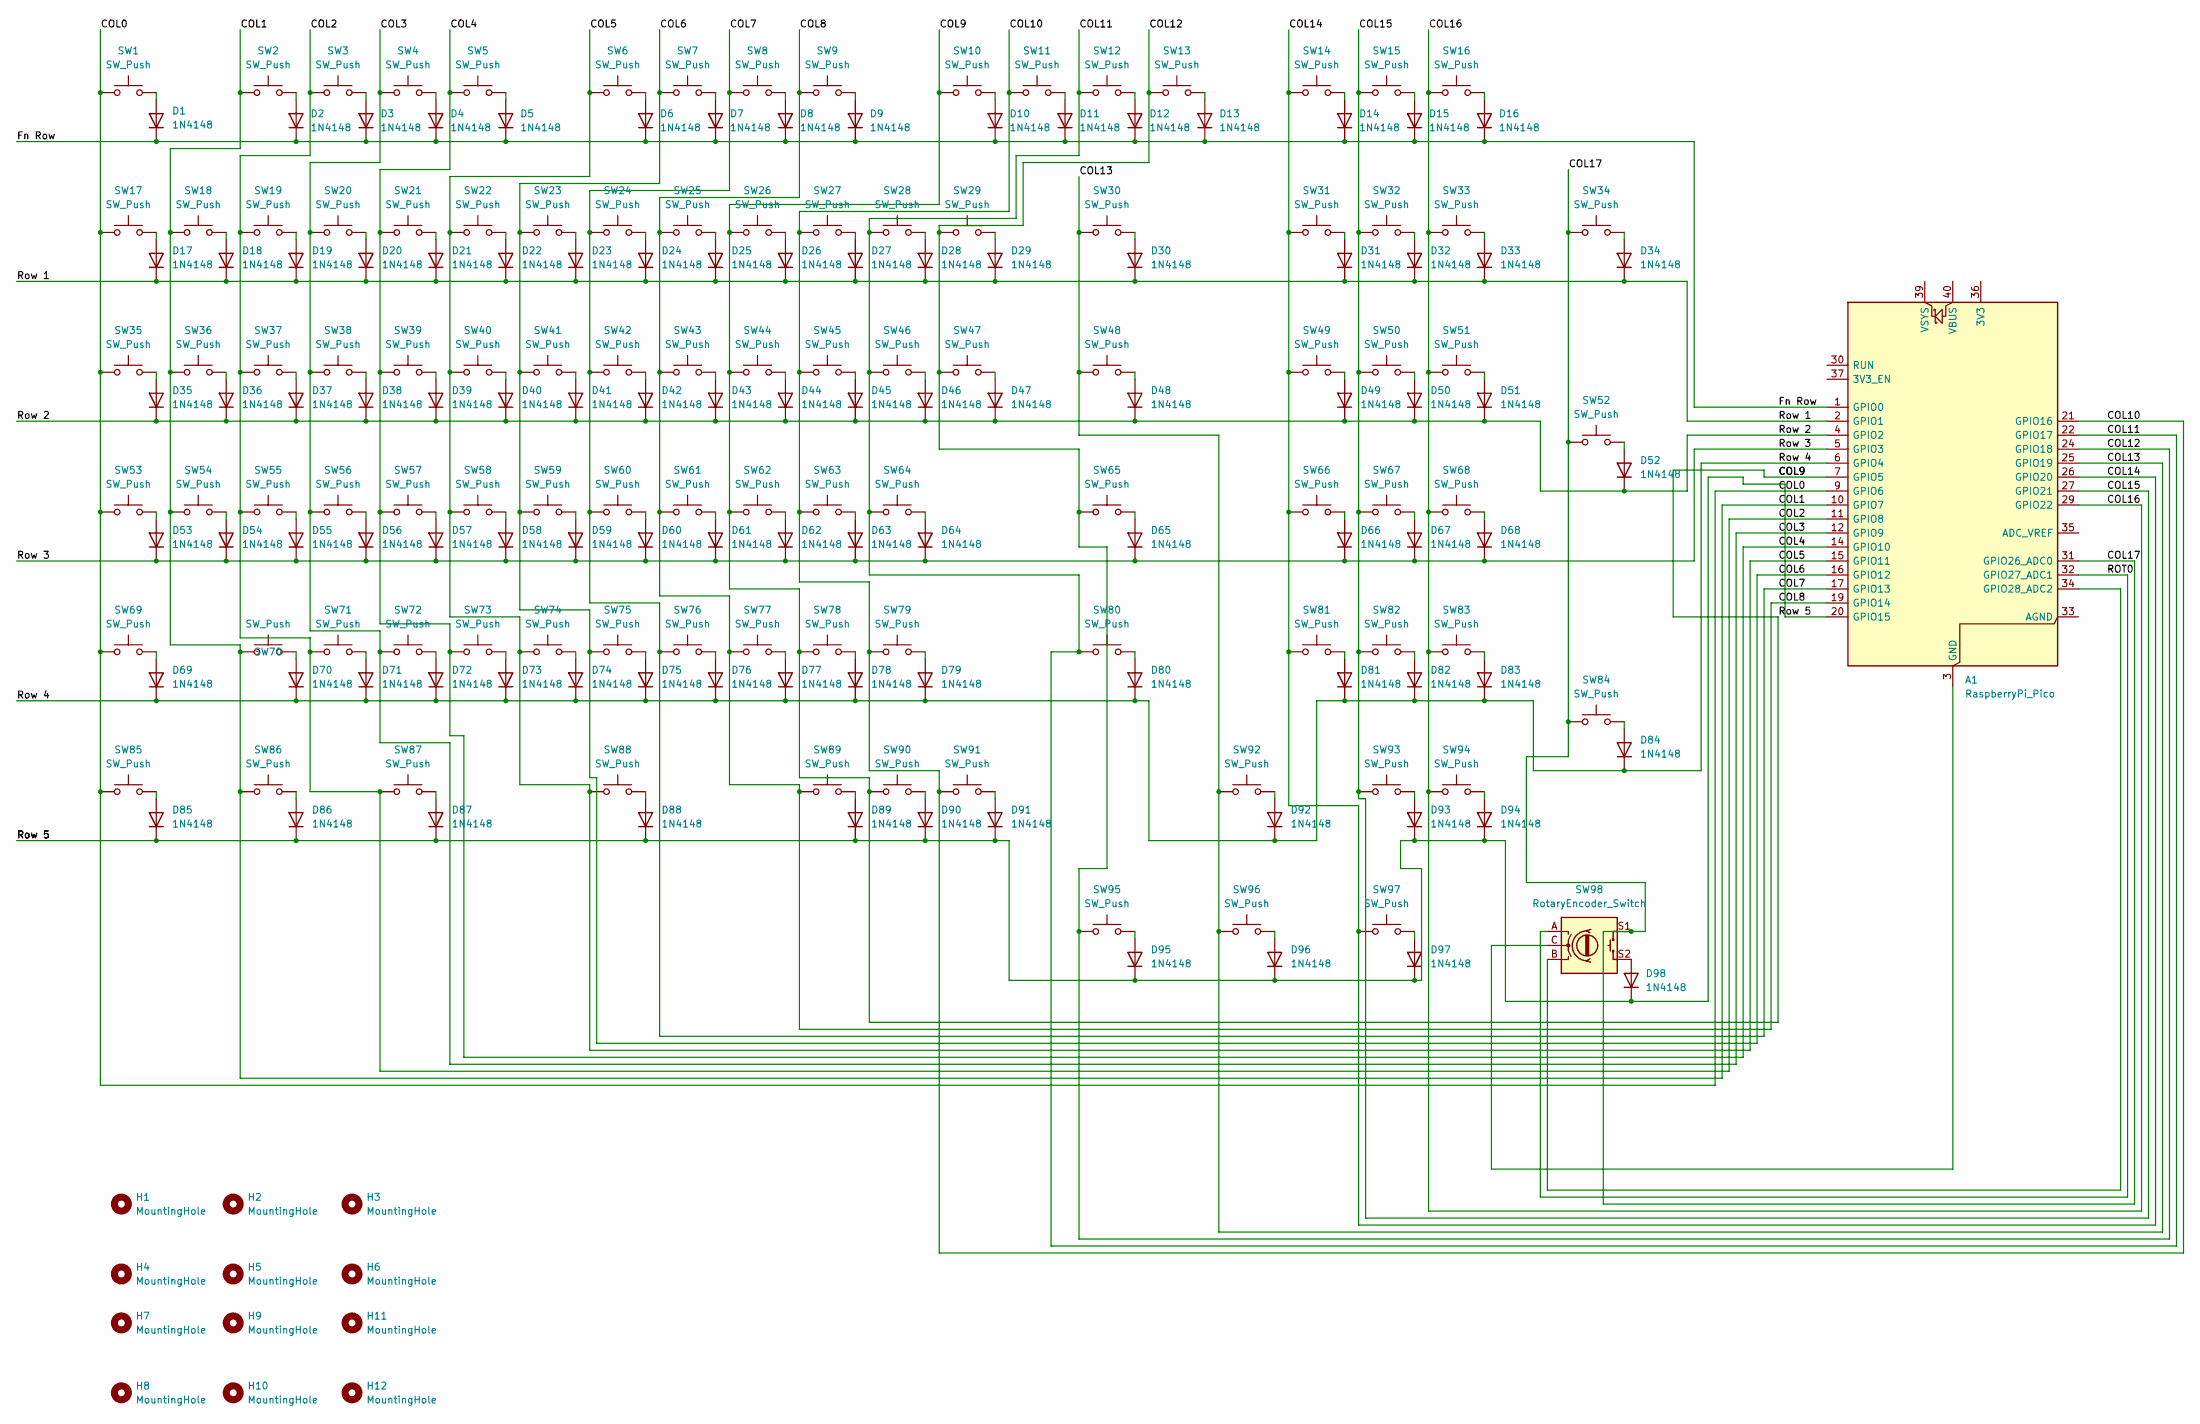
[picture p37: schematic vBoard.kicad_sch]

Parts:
A1: RaspberryPi_Pico; RaspberryPi_Pico_Common_THT
D1, D2, D3, D4, D5, D6, D7, D8, D9, D10, D11, D12, D13, D14, D15, D16, D17, D18, D19, D20, D21, D22, D23, D24, D25, D26, D27, D28, D29, D30, D31, D32, D33, D34, D35, D36, D37, D38, D39, D40, D41, D42, D43, D44, D45, D46, D47, D48, D49, D50, D51, D52, D53, D54, D55, D56, D57, D58, D59, D60, D61, D62, D63, D64, D65, D66, D67, D68, D69, D70, D71, D72, D73, D74, D75, D76, D77, D78, D79, D80, D81, D82, D83, D84, D85, D86, D87, D88, D89, D90, D91, D92, D93, D94, D95, D96, D97, D98: 1N4148; D_SOD-123
H1, H2, H3, H4, H5, H6, H7, H8, H9, H10, H11, H12: MountingHole; MountingHole_3.2mm_M3
SW1, SW2, SW3, SW4, SW5, SW6, SW7, SW8, SW9, SW10, SW11, SW12, SW13, SW14, SW15, SW16, SW17, SW18, SW19, SW20, SW21, SW22, SW23, SW24, SW25, SW26, SW27, SW28, SW29, SW30, SW31, SW32, SW33, SW34, SW35, SW36, SW37, SW38, SW39, SW40, SW41, SW42, SW43, SW44, SW45, SW46, SW47, SW48, SW49, SW50, SW51, SW52, SW53, SW54, SW55, SW56, SW57, SW58, SW59, SW60, SW61, SW62, SW63, SW64, SW65, SW66, SW67, SW68, SW69, SW70, SW71, SW72, SW73, SW74, SW75, SW76, SW77, SW78, SW79, SW80, SW81, SW82, SW83, SW84, SW85, SW86, SW87, SW88, SW89, SW90, SW91, SW92, SW93, SW94, SW95, SW96, SW97: SW_Push; SW_MX_HS_CPG151101S11_1u
SW98: RotaryEncoder_Switch; RotaryEncoder_Alps_EC11E-Switch_Vertical_H20mm

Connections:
/COL0: A1.9 (GPIO6), SW1.1, SW17.1, SW35.1, SW53.1, SW69.1, SW85.1
/COL1: A1.10 (GPIO7), SW2.1, SW18.1, SW36.1, SW54.1, SW70.1, SW86.1
/COL2: A1.11 (GPIO8), SW3.1, SW19.1, SW37.1, SW55.1, SW71.1, SW87.1
/COL3: A1.12 (GPIO9), SW4.1, SW20.1, SW38.1, SW56.1, SW72.1
/COL4: A1.14 (GPIO10), SW5.1, SW21.1, SW39.1, SW57.1, SW73.1
/COL5: A1.15 (GPIO11), SW6.1, SW22.1, SW40.1, SW58.1, SW74.1, SW88.1
/COL6: A1.16 (GPIO12), SW7.1, SW23.1, SW41.1, SW59.1, SW75.1
/COL7: A1.17 (GPIO13), SW8.1, SW24.1, SW42.1, SW60.1, SW76.1
/COL8: A1.19 (GPIO14), SW9.1, SW25.1, SW43.1, SW61.1, SW77.1, SW89.1
/COL9: A1.7 (GPIO5), A1.20 (GPIO15), D85.1 (K), D86.1 (K), D87.1 (K), D88.1 (K), D89.1 (K), D90.1 (K), D91.1 (K), D93.1 (K), D94.1 (K), D95.1 (K), D96.1 (K), D97.1 (K), D98.1 (K), SW10.1, SW26.1, SW44.1, SW62.1, SW78.1, SW90.1
/COL10: A1.21 (GPIO16), SW11.1, SW27.1, SW45.1, SW63.1, SW79.1, SW91.1
/COL11: A1.22 (GPIO17), SW12.1, SW28.1, SW46.1, SW64.1, SW80.1
/COL12: A1.24 (GPIO18), SW13.1, SW29.1, SW47.1, SW65.1, SW95.1
/COL13: A1.25 (GPIO19), SW30.1, SW48.1, SW92.1, SW96.1
/COL14: A1.26 (GPIO20), SW14.1, SW31.1, SW49.1, SW66.1, SW81.1, SW97.1
/COL15: A1.27 (GPIO21), SW15.1, SW32.1, SW50.1, SW67.1, SW82.1, SW93.1
/COL16: A1.29 (GPIO22), SW16.1, SW33.1, SW51.1, SW68.1, SW83.1, SW94.1
/COL17: A1.31 (GPIO26_ADC0), SW34.1, SW52.1, SW84.1, SW98.S1
/Fn Row: A1.1 (GPIO0), D1.1 (K), D2.1 (K), D3.1 (K), D4.1 (K), D5.1 (K), D6.1 (K), D7.1 (K), D8.1 (K), D9.1 (K), D10.1 (K), D11.1 (K), D12.1 (K), D13.1 (K), D14.1 (K), D15.1 (K), D16.1 (K)
/ROT0: A1.32 (GPIO27_ADC1), SW98.A
/Row 1: A1.2 (GPIO1), D17.1 (K), D18.1 (K), D19.1 (K), D20.1 (K), D21.1 (K), D22.1 (K), D23.1 (K), D24.1 (K), D25.1 (K), D26.1 (K), D27.1 (K), D28.1 (K), D29.1 (K), D30.1 (K), D31.1 (K), D32.1 (K), D33.1 (K), D34.1 (K)
/Row 2: A1.4 (GPIO2), D35.1 (K), D36.1 (K), D37.1 (K), D38.1 (K), D39.1 (K), D40.1 (K), D41.1 (K), D42.1 (K), D43.1 (K), D44.1 (K), D45.1 (K), D46.1 (K), D47.1 (K), D48.1 (K), D49.1 (K), D50.1 (K), D51.1 (K), D52.1 (K)
/Row 3: A1.5 (GPIO3), D53.1 (K), D54.1 (K), D55.1 (K), D56.1 (K), D57.1 (K), D58.1 (K), D59.1 (K), D60.1 (K), D61.1 (K), D62.1 (K), D63.1 (K), D64.1 (K), D65.1 (K), D66.1 (K), D67.1 (K), D68.1 (K)
/Row 4: A1.6 (GPIO4), D69.1 (K), D70.1 (K), D71.1 (K), D72.1 (K), D73.1 (K), D74.1 (K), D75.1 (K), D76.1 (K), D77.1 (K), D78.1 (K), D79.1 (K), D80.1 (K), D81.1 (K), D82.1 (K), D83.1 (K), D84.1 (K), D92.1 (K)
unnamed: A1.3 (GND), A1.8 (GND), A1.13 (GND), A1.18 (GND), A1.23 (GND), A1.28 (GND), A1.38 (GND), SW98.C
unnamed: A1.34 (GPIO28_ADC2), SW98.B
unnamed: D1.2 (A), SW1.2
unnamed: D2.2 (A), SW2.2
unnamed: D3.2 (A), SW3.2
unnamed: D4.2 (A), SW4.2
unnamed: D5.2 (A), SW5.2
unnamed: D6.2 (A), SW6.2
unnamed: D7.2 (A), SW7.2
unnamed: D8.2 (A), SW8.2
unnamed: D9.2 (A), SW9.2
unnamed: D10.2 (A), SW10.2
unnamed: D11.2 (A), SW11.2
unnamed: D12.2 (A), SW12.2
unnamed: D13.2 (A), SW13.2
unnamed: D14.2 (A), SW14.2
unnamed: D15.2 (A), SW15.2
unnamed: D16.2 (A), SW16.2
unnamed: D17.2 (A), SW17.2
unnamed: D18.2 (A), SW18.2
unnamed: D19.2 (A), SW19.2
unnamed: D20.2 (A), SW20.2
unnamed: D21.2 (A), SW21.2
unnamed: D22.2 (A), SW22.2
unnamed: D23.2 (A), SW23.2
unnamed: D24.2 (A), SW24.2
unnamed: D25.2 (A), SW25.2
unnamed: D26.2 (A), SW26.2
unnamed: D27.2 (A), SW27.2
unnamed: D28.2 (A), SW28.2
unnamed: D29.2 (A), SW29.2
unnamed: D30.2 (A), SW30.2
unnamed: D31.2 (A), SW31.2
unnamed: D32.2 (A), SW32.2
unnamed: D33.2 (A), SW33.2
unnamed: D34.2 (A), SW34.2
unnamed: D35.2 (A), SW35.2
unnamed: D36.2 (A), SW36.2
unnamed: D37.2 (A), SW37.2
unnamed: D38.2 (A), SW38.2
unnamed: D39.2 (A), SW39.2
unnamed: D40.2 (A), SW40.2
unnamed: D41.2 (A), SW41.2
unnamed: D42.2 (A), SW42.2
unnamed: D43.2 (A), SW43.2
unnamed: D44.2 (A), SW44.2
unnamed: D45.2 (A), SW45.2
unnamed: D46.2 (A), SW46.2
unnamed: D47.2 (A), SW47.2
unnamed: D48.2 (A), SW48.2
unnamed: D49.2 (A), SW49.2
unnamed: D50.2 (A), SW50.2
unnamed: D51.2 (A), SW51.2
unnamed: D52.2 (A), SW52.2
unnamed: D53.2 (A), SW53.2
unnamed: D54.2 (A), SW54.2
unnamed: D55.2 (A), SW55.2
unnamed: D56.2 (A), SW56.2
unnamed: D57.2 (A), SW57.2
unnamed: D58.2 (A), SW58.2
unnamed: D59.2 (A), SW59.2
unnamed: D60.2 (A), SW60.2
unnamed: D61.2 (A), SW61.2
unnamed: D62.2 (A), SW62.2
unnamed: D63.2 (A), SW63.2
unnamed: D64.2 (A), SW64.2
unnamed: D65.2 (A), SW65.2
unnamed: D66.2 (A), SW66.2
unnamed: D67.2 (A), SW67.2
unnamed: D68.2 (A), SW68.2
unnamed: D69.2 (A), SW69.2
unnamed: D70.2 (A), SW70.2
unnamed: D71.2 (A), SW71.2
unnamed: D72.2 (A), SW72.2
unnamed: D73.2 (A), SW73.2
unnamed: D74.2 (A), SW74.2
unnamed: D75.2 (A), SW75.2
unnamed: D76.2 (A), SW76.2
unnamed: D77.2 (A), SW77.2
unnamed: D78.2 (A), SW78.2
unnamed: D79.2 (A), SW79.2
unnamed: D80.2 (A), SW80.2
unnamed: D81.2 (A), SW81.2
unnamed: D82.2 (A), SW82.2
unnamed: D83.2 (A), SW83.2
unnamed: D84.2 (A), SW84.2
unnamed: D85.2 (A), SW85.2
unnamed: D86.2 (A), SW86.2
unnamed: D87.2 (A), SW87.2
unnamed: D88.2 (A), SW88.2
unnamed: D89.2 (A), SW89.2
unnamed: D90.2 (A), SW90.2
unnamed: D91.2 (A), SW91.2
unnamed: D92.2 (A), SW92.2
unnamed: D93.2 (A), SW93.2
unnamed: D94.2 (A), SW94.2
unnamed: D95.2 (A), SW95.2
unnamed: D96.2 (A), SW96.2
unnamed: D97.2 (A), SW97.2
unnamed: D98.2 (A), SW98.S2

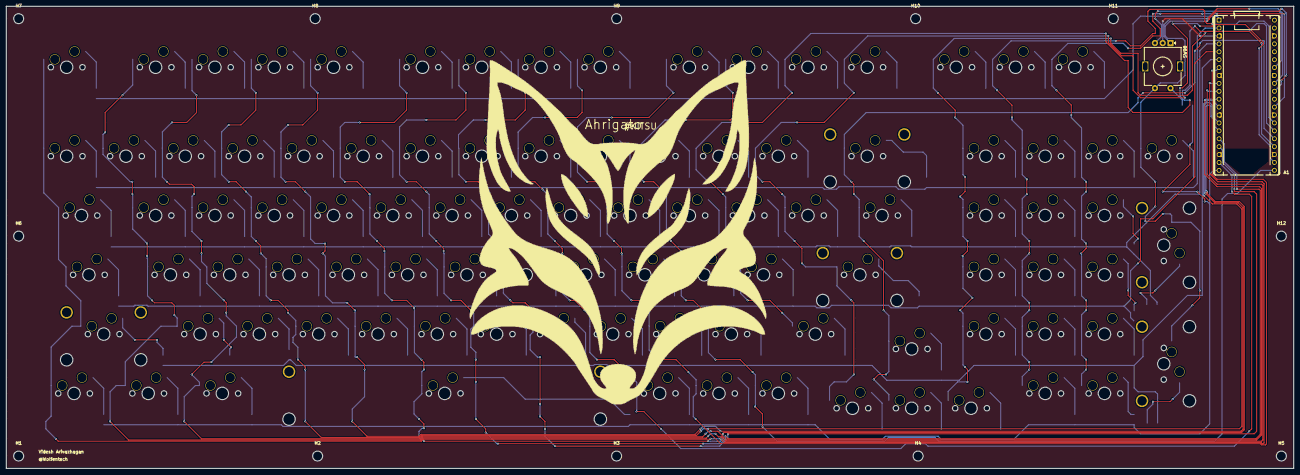
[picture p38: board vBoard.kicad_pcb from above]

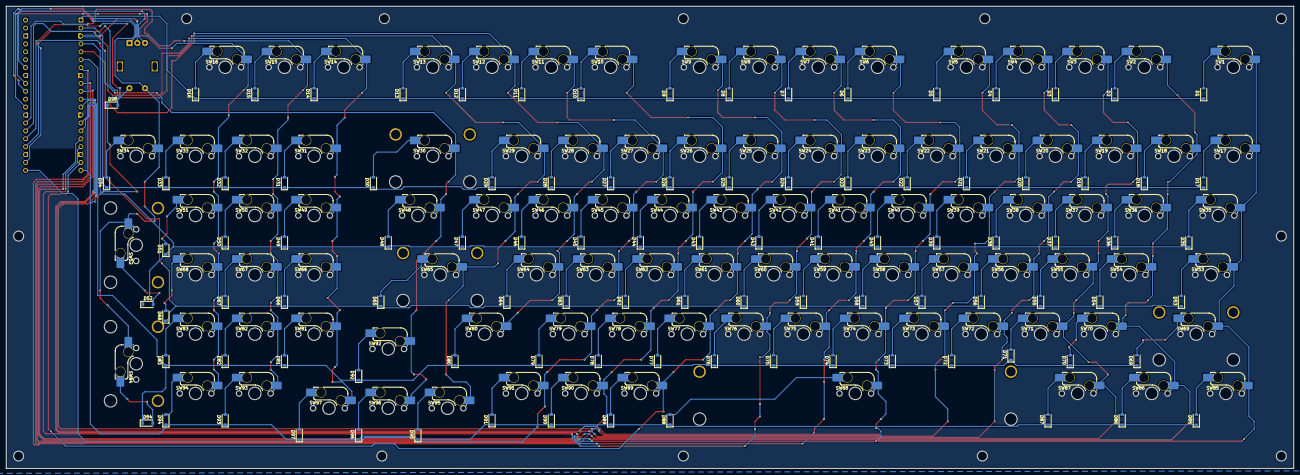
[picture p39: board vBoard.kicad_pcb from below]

Board: 2 copper layers, 413.5 x 148.4 mm, 215 parts (197 on the bottom side), 124 nets.

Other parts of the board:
S1, S2, S3, S4, S5: MX_stab; STAB_MX_P_2u
S11: MX_stab; STAB_MX_P_6.25u

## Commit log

2026-09-15 Initial setup. Installing KiCad and Libraries and setting up my Github Repo!
2026-09-21 caught up on journalling...
    [bom.csv, botplate.dxf, closerlayer.dxf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]
2026-09-21 messed up naming lmao
    [switchlayer.dxf, switchlayerv2.dxf]
2026-09-21 Added pictures and remembered to add my pcb files.
    [bom.csv, vBoard.kicad_pcb, vBoard.kicad_sch]
2026-09-21 ill journal tomorrow
    [vBoard.kicad_sch]
2026-09-24 Finally updated logs
    [bom.csv, vBoard.kicad_pcb, vBoard.kicad_sch]
2026-09-26 journaling kicad. Will work on cad after pcb.
    [vBoard.kicad_pcb, vBoard.kicad_sch]
2026-09-27 Journaling and got some more work done.
    [vBoard.kicad_pcb, vBoard.kicad_sch]
2026-09-28 DRC fixes.
    [vBoard.kicad_pcb, vBoard.kicad_sch]
2026-09-28 Exports and Orders :3
    [vBoard-B_Cu.gbr, vBoard-B_Mask.gbr, vBoard-B_Paste.gbr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]
2026-09-28 I messed up.
    [EC11.STEP, MX.STEP, vBoard.kicad_pcb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]
2026-09-28 Last things Ill work on for PCB wise.
    [vBoard-B_Cu.gbr, vBoard-B_Mask.gbr, vBoard-B_Paste.gbr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]
2026-09-28 Cad started
    [2U Stabilizer.step, 6.25U Stabilizer.step, 7U Stabilizer.step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]
2026-09-28 Cad start
2026-09-28 Started firmware and finished Cadding :3
    [Bottom Plate.step, Switch Plate.step, Top Frame.step]
2026-09-29 Done with Physical stuff. Prototype for Firmware done.
    [bom.csv]
2026-10-14 Add pricing section to README
    Added pricing section with PCB fabrication and Amazon cart images.
2026-10-22 Entire assembly :3
2026-10-22 Assembly... with Keycaps!
2026-10-23 Added Pricing for BOM
2026-10-26 Found cheaper board
